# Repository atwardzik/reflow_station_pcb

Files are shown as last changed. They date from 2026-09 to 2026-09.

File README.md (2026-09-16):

# Reflow Station

This project is currently in a prototype stage. It features PCB project of
basic reflow station utilizing 4 phase-controlled triacs steering with attached
heaters. The temperature is controlled by the STM32F469VIT6 MCU with attached
ADS1118 thermocouple interfaces.

## Schematic

Circuit Diagram

## License
CC BY-NC-SA 4.0

Copyright (C) 2026, Artur Twardzik

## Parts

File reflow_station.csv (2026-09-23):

Reference | Qty | Value | Mfr.No | Replacement_Mfr.No | Description | Package | Footprint | Datasheet | Supplier | Supplier_Link | JLCPCB_PartNo | Additional_Info
C1 | 1 | 100n 1kV | R474N31005001K |  | Unpolarized capacitor: 100nF 440VAC X2 10% polypropylene |  | reflow_station_library:R474N31005001K | https://www.tme.eu/Document/74c9fedd37d4aad2db2d48e5f5684533/Datasheet-R474N31005001K.pdf | TME | https://www.tme.eu/pl/details/r474n31005001k/kondensatory-foliowe-tht/kemet/
C2,C13,C14,C17,C23,C25,C26,C28,C29,C31,C33,C34,C36,C37,C39,C41,C46,C47,C48,C49,C50,C51,C52,C53,C54,C56,C58,C59 | 28 | 100n | CL05B104KB54PNC |  | Unpolarized capacitor: 100nF 50V X7R ±10% ceramic | 0402 | reflow_station_library:C_0402_1005Metric |  | JLCPCB | https://jlcpcb.com/partdetail/291005-CL05B104KB54PNC/C307331 | C307331
C3 | 1 | 47u | C2220C476M3R2CAUTO |  | Unpolarized capacitor: 47uF 25V X7R ±20% ceramic | 2220 | reflow_station_library:C_2220_5750Metric_Pad1.97x5.40mm_HandSolder | https://www.tme.eu/Document/458b498f8990c968c05ae31cff6842ca/C2220C476M3R2CAUTO.pdf | TME | https://www.tme.eu/pl/en/details/c2220c476m3r2cauto/mlcc-smd-capacitors/kemet/
C4,C7 | 2 | 10u | CL31A106KBHNNNE |  | Unpolarized capacitor: 10uF 50V X5R 10% ceramic | 1206 | reflow_station_library:C_1206_3216Metric_Pad1.33x1.80mm_HandSolder |  | JLCPCB | https://jlcpcb.com/partdetail/14236-CL31A106KBHNNNE/C13585 | C13585
C5,C40 | 2 | 47u | CL31A476MPHNNNE |  | Unpolarized capacitor: 47uF 10V X5R 20% ceramic | 1206 | reflow_station_library:C_1206_3216Metric_Pad1.33x1.80mm_HandSolder |  | JLCPCB | https://jlcpcb.com/partdetail/97327-CL31A476MPHNNNE/C96123 | C96123
C6,C11 | 2 | 430p | GCM1555C1H431JA16D |  | Unpolarized capacitor: 430pF 50V 5% ceramic | 0402 | reflow_station_library:C_0402_1005Metric |  | JLCPCB | https://jlcpcb.com/partdetail/2285629-GCM1555C1H431JA16D/C2193561 | C2193561
C8 | 1 | 22u | CL31A226KAHNNNE |  | Unpolarized capacitor: 22uF 25V X5R 10% ceramic | 1206 | reflow_station_library:C_1206_3216Metric |  | JLCPCB | https://jlcpcb.com/partdetail/13537-CL31A226KAHNNNE/C12891 | C12891
C9 | 1 | 470p | 0603B471K500NT |  | Unpolarized capacitor: 470pF 50V X7R 10% ceramic | 0603 | reflow_station_library:C_0603_1608Metric |  | JLCPCB | https://jlcpcb.com/partdetail/1972-0603B471K500NT/C1620 | C1620
C10 | 1 | 220u | RVT1V221M0810ZY |  | Polarized capacitor: 220uF 50V 20% aluminum electrolytic | D8xL10.5mm | reflow_station_library:CP_Elec_8x10.5 |  | JLCPCB | https://jlcpcb.com/partdetail/ChengTao-RVT1V221M0810ZY/C46527540 | C46527540
C12,C45 | 2 | 4.7u | CL21A475KAQNNNE |  | Unpolarized capacitor: 4.7uF 25V X5R 10% ceramic | 0805 | reflow_station_library:C_0805_2012Metric |  | JLCPCB | https://jlcpcb.com/partdetail/2131-CL21A475KAQNNNE/C1779 | C1779
C15,C16,C24,C27,C32,C35,C42,C43,C44,C57,C60 | 11 | 1u | CL05A105KA5NQNC |  | Unpolarized capacitor: 1uF 25V X5R 10% ceramic | 0402 | reflow_station_library:C_0402_1005Metric |  | JLCPCB | https://jlcpcb.com/partdetail/53938-CL05A105KA5NQNC/C52923 | C52923
C18 | 1 | 2.2n | 0603B222K500NT |  | Unpolarized capacitor: 2.2nF 50V X7R 10% ceramic | 0603 | reflow_station_library:C_0603_1608Metric |  | JLCPCB | https://jlcpcb.com/partdetail/1956-0603B222K500NT/C1604 | C1604
C19,C20,C21,C22 | 4 | 10n 305V X2 | B32921C3103M189 |  | Unpolarized capacitor: 10nF 305VAC X2 20% polypropylene |  | reflow_station_library:B32921C3103M000 | https://www.tme.eu/Document/b68f0c52455388a5f3f01ef7d5bbddae/x2_b32921_928.pdf | TME | https://www.tme.eu/pl/details/b32921c3103m189/kondensatory-foliowe-tht/tdk/
C30,C38 | 2 | 10n | CL05B103KB5NNNC |  | Unpolarized capacitor: 10nF 50V X7R 10% ceramic | 0402 | reflow_station_library:C_0402_1005Metric |  | JLCPCB | https://jlcpcb.com/partdetail/15869-CL05B103KB5NNNC/C15195 | C15195
C55,C63,C64 | 3 | 2.2u | CL10A225KO8NNNC |  | Unpolarized capacitor: 2.2uF 16V X5R 10% ceramic | 0603 | reflow_station_library:C_0603_1608Metric |  | JLCPCB | https://jlcpcb.com/partdetail/24366-CL10A225KO8NNNC/C23630 | C23630
C61,C62 | 2 | 10p | CL05C100JB5NNNC |  | Unpolarized capacitor: 10pF 50V C0G 5% ceramic | 0402 | reflow_station_library:C_0402_1005Metric |  | JLCPCB | https://jlcpcb.com/partdetail/33914-CL05C100JB5NNNC/C32949 | C32949
C65,C66 | 2 | 1.5p | 0402CG1R5C500NT |  | Unpolarized capacitor: 1.5pF 50V C0G ceramic | 0402 | reflow_station_library:C_0402_1005Metric |  | JLCPCB | https://jlcpcb.com/partdetail/1904-0402CG1R5C500NT/C1552 | C1552
D1,D2,D4,D10,D11,D13 | 6 | LED | KT-0603R |  | Light emitting diode: red | 0603 | reflow_station_library:LED_0603_1608Metric |  | JLCPCB | https://jlcpcb.com/partdetail/Hubei_KENTOElec-KT0603R/C2286 | C2286
D3 | 1 | MB10S | MB10S-50MIL |  | Single-Phase Diode Bridge Rectifier | MBS | reflow_station_library:SOP240P700X300-4N |  | JLCPCB | https://jlcpcb.com/partdetail/2865-MB10S50MIL/C2488 | C2488
D5 | 1 | BAT54S | BAT54SLT1G |  | Dual Series Schottky Barrier Diodes | SOT-23 | reflow_station_library:SOT-23 |  | JLCPCB | https://jlcpcb.com/partdetail/onsemi-BAT54SLT1G/C19726 | C19726
D6,D7,D8 | 3 | 1N4148WS |  |  | 75V 0.15A Fast switching Diode, SOD-323 |  | Diode_SMD:D_SOD-323 | https://www.vishay.com/docs/85751/1n4148ws.pdf
D9,D12,D14 | 3 | LED | KT-0805G,KT-0805W,KT-0805Y |  | Light emitting diode: green,Light emitting diode: white,Light emitting diode: yellow | 0805 | reflow_station_library:LED_0805_2012Metric |  | JLCPCB | https://jlcpcb.com/partdetail/Hubei_KENTOElec-KT0805G/C2297,https://jlcpcb.com/partdetail/Hubei_KENTOElec-KT0805W/C34499,https://jlcpcb.com/partdetail/Hubei_K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 | C2296,C2297,C34499
HS1,HS2,HS3,HS4 | 4 | Heatsink | SK 75 50 SA-TO 220 |  | Heatsink with electrical connection, 2 pin |  | reflow_station_library:Heatsink_Stonecold_HS-132_32x14mm_2xFixation1.5mm |  | TME | https://www.tme.eu/pl/en/details/sk75_50_sa-to220/heatsinks/fischer-elektronik/sk-75-50-sa-to-220/
IC1 | 1 | MP100LGN-Z | MP100LGN-Z |  | AC/DC Converters Offline Inductorless regulator, Low EMI | SOIC-8 | reflow_station_library:SOIC127P600X170-9N | https://www.monolithicpower.com/en/documentview/productdocument/index/version/2/document_type/Datasheet/lang/en/sku/MP100L/document_id/11 | JLCPCB | https://jlcpcb.com/partdetail/Monolithic_PowerSystems-MP100LGNZ/C17183900 | C17183900
IC2 | 1 | AMC23C10DWVR | AMC23C10DWVR |  | Analog Comparators Fast-response, reinforced, isolated differential comparator with open-drain and push-pull outputs | SOIC-8 | reflow_station_library:SOIC127P1150X280-8N | https://www.ti.com/lit/ds/symlink/amc23c10.pdf?HQS=dis-mous-null-mousermode-dsf-pf-null-wwe&ts=1691395362663 | JLCPCB | https://jlcpcb.com/partdetail/TexasInstruments-AMC23C10DWVR/C5943166 | C5943166
J1 | 1 | 1731734 | 1731734 |  | GMKDS 3/ 3-7,62 - Printed circuit board terminal, nominal current: 24 A, rated voltage (III/2): 630 V, nominal cross section: 2.5 mm<sup>2</sup>, number of potentials: 3, number of rows: 1, number of positions per row: 3, product range: GMKDS 3, pitch: 7.62 mm, connection method: Screw connection with tension sleeve, screw head form: L Slotted, mounting: Wave soldering, conductor/PCB connection direction: 0 , color: green, Pin layout: Linear pinning, Solder pin [P]: 5 mm, number of solder pins per potentia |  | reflow_station_library:1731734 | https://www.phoenixcontact.com/en-us/products/printed-circuit-board-terminal-gmkds-3-3-762-1731734?type=pdf | TME | https://www.tme.eu/pl/details/gmkds3_3-7.62/listwy-zaciskowe-do-druku/phoenix-contact/1731734/
J2,J3,J4,J5 | 4 | 1707027 | 1731721 |  | GMKDS 3/ 2-7,62 - Printed circuit board terminal, nominal current: 24 A, rated voltage (III/2): 630 V, nominal cross section: 2.5 mm<sup>2</sup>, number of potentials: 2, number of rows: 1, number of positions per row: 2, product range: GMKDS 3, pitch: 7.62 mm, connection method: Screw connection with tension sleeve, screw head form: L Slotted, mounting: Wave soldering, conductor/PCB connection direction: 0 , color: green, Pin layout: Linear pinning, Solder pin [P]: 5 mm, number of solder pins per potentia |  | reflow_station_library:1731721 | https://www.phoenixcontact.com/en-us/products/printed-circuit-board-terminal-gmkds-3-2-762-1731721?type=pdf | TME | https://www.tme.eu/pl/details/gmkds3_2-7.62/listwy-zaciskowe-do-druku/phoenix-contact/1731721/
J6,J7,J8,J9 | 4 | DG301-5.0-02P-12-00A_H_ | DG301-5.0-02P-12-00A(H) |  | PCB terminal block; angled 90; 5mm; ways: 2; on PCBs; 1.5mm2; blue |  | reflow_station_library:DG3015002P1200AH | https://www.tme.com/Document/72ad9f371bb0c16572574ac47903b3a1/DG301-5.0.pdf | TME | https://www.tme.eu/pl/en/details/dg301-5.0-2p12/pcb-terminal-blocks/degson-electronics/dg301-5-0-02p-12-00a-h/
J10 | 1 | USB_A |  |  | USB Type A connector |  | reflow_station_library:USB_A_Molex_67643_Horizontal | https://www.tme.eu/Document/28949cd128764504b86904217dc06d83/MX-67643-0910.pdf | TME | https://www.tme.eu/pl/en/details/mx-67643-0910/usb-ieee1394-connectors/molex/67643-0910/
J11 | 1 | USB_C_Receptacle_USB2.0_16P | USB-TYPE-C-018 |  | USB 2.0-only 16P Type-C Receptacle connector |  | reflow_station_library:USB-C_SMD-TYPE-C-31-M-12 | https://www.usb.org/sites/default/files/documents/usb_type-c.zip | JLCPCB | https://jlcpcb.com/partdetail/DEALON-USB_TYPE_C018/C2927038 | C2927038
J12 | 1 | Conn_ARM_JTAG_SWD_10 | HX JN1.27-2x5P ZZ H4.9 |  | Cortex Debug Connector, standard ARM Cortex-M SWD and JTAG interface |  | reflow_station_library:CONN-TH_10P-P1.27_HX-JN1.27-2X5P-ZZ-H4.9 | http://infocenter.arm.com/help/topic/com.arm.doc.ddi0314h/DDI0314H_coresight_components_trm.pdf | JLCPCB | https://jlcpcb.com/partdetail/hanxia-HX_JN1_27_2x5P_ZZ_H49/C42372547 | C42372547
J13 | 1 | F52Q-1A7H1-11015 | F52Q-1A7H1-11015 |  | Flex Connector, 1.00mm Pitch, Height 2.00mm, Right angle, Slider type, ZIF, Upper contact, 15 position , Without MYLAR |  | reflow_station_library:F52Q1A7H111015 | https://cdn.amphenol-cs.com/media/wysiwyg/files/drawing/f52q.pdf | MOUSER | https://www.mouser.pl/en/ProductDetail/Amphenol-Aorora/F52Q-1A7H1-11015?qs=xZ%2FP%252Ba9zWqZztqleDXVpTA%3D%3D
L1,L2,L3,L4,L5 | 5 | 33R @ 100MHz | BLM18PG330SN1D |  | Inductor: 33R @ 100MHz, EMI filter |  | reflow_station_library:L_1206_3216Metric_Pad1.22x1.90mm_HandSolder |  | JLCPCB | https://jlcpcb.com/partdetail/MurataElectronics-BLM18PG330SN1D/C88984 | C88984
L6 | 1 | 600R @ 100MHz | FCM1608KF-601T03 | BLM18AG601SN1D | Inductor: 600R @ 100MHz, digital and analog voltage filtering |  | reflow_station_library:L_0603_1608Metric |  | JLCPCB | https://jlcpcb.com/partdetail/TAITECH-FCM1608KF601T03/C141723 | C141723 | C19330 is in greater availability
LS1 | 1 | PS1240P02BT | PS1240P02BT |  | Piezoelectric Buzzers, Sound Pressure Level=70dB min, Freq.=4000Hz nom |  | reflow_station_library:PS1240P02BT | https://product.tdk.com/system/files/dam/doc/product/sw_piezo/sw_piezo/piezo-buzzer/catalog/piezoelectronic_buzzer_ps_en.pdf | MOUSER | https://www.mouser.pl/en/ProductDetail/TDK/PS1240P02BT?qs=d7g9p1yFhWaZXSY9MjKMkw%3D%3D
M1,M2,M3,M4 | 4 | Fan_CPU_4pin | B4B-PH-K-S (LF)(SN) |  | Connector: wire-board socket male 4 pin 2A |  | reflow_station_library:JST_PH_B4B-PH-K_1x04_P2.00mm_Vertical | https://www.tme.eu/Document/bde47a97a79ef7b2143e7f603cd40725/PH.pdf | TME | https://www.tme.eu/pl/details/b4b-ph-k-s/zlacza-sygnalowe-raster-2-00mm/jst/b4b-ph-k-s-lf-sn/
Q1,Q2,Q3,Q4 | 4 | BTA16-600B | BTA16-600BRG | BTA08-600BRG; T3035H-8I | Triac: 16A 50mA 600V pin 2 bent | TO-220 | reflow_station_library:TO-220-3_Vertical_Staggered | https://www.tme.eu/Document/f612b70f30f519380bd53616c2407b4b/BTA16_BTB16_T16xx.pdf | TME | https://www.tme.eu/pl/en/details/bta16-600brg/triacs/stmicroelectronics/ |  | T3035H-8I has Igt=35mA but has max Tj at 150 'C
Q5 | 1 | KSC1815YTA | KSC1815YTA |  | Bipolar transistor: NPN 50V 0.15 0.4W | TO92 | reflow_station_library:TO-92L_Inline_Wide | https://www.tme.eu/Document/4d6f25bc413f5cea15d81ed94c626a86/KSC1815.pdf | TME | https://www.tme.eu/pl/en/details/ksc1815yta/npn-tht-transistors/onsemi/
R1,R59 | 2 | 1k | 0402WGF1001TCE |  | Resistor: 1kOhm 50V 62.5mW 1% | 0402 | reflow_station_library:R_0402_1005Metric |  | JLCPCB | https://jlcpcb.com/partdetail/12256-0402WGF1001TCE/C11702 | C11702
R2 | 1 | 510 | 0402WGF5100TCE |  | Resistor: 510Ohm 50V 62.5mW 1% | 0402 | reflow_station_library:R_0402_1005Metric |  | JLCPCB | https://jlcpcb.com/partdetail/25866-0402WGF5100TCE/C25123 | C25123
R3 | 1 | 523k | 0402WGF5233TCE |  | Resistor: 523kOhm 50V 62.5mW 1% | 0402 | reflow_station_library:R_0402_1005Metric |  | JLCPCB | https://jlcpcb.com/partdetail/27760-0402WGF5233TCE/C27011 | C27011
R4 | 1 | 100 3W | PMR03SJ0101A19 |  | Resistor: 100Ohm 750V 3W 5% power metal |  | reflow_station_library:R_Axial_DIN0516_L15.5mm_D5.0mm_P20.32mm_Horizontal |  | TME | https://www.tme.eu/pl/details/pmr3s-100r/rezystory-tht/royalohm/pmr03sj0101a19/
R5,R6,R7,R12,R13 | 5 | 100k | 0402WGF1003TCE |  | Resistor: 100kOhm 50V 62.5mW 1% | 0402 | reflow_station_library:R_0402_1005Metric |  | JLCPCB | https://jlcpcb.com/partdetail/26484-0402WGF1003TCE/C25741 | C25741
R8,R60,R61,R62,R63,R64,R65 | 7 | 330 | 0402WGF3300TCE |  | Resistor: 330Ohm 50V 62.5mW 1% | 0402 | reflow_station_library:R_0402_1005Metric |  | JLCPCB | https://jlcpcb.com/partdetail/25847-0402WGF3300TCE/C25104 | C25104
R9 | 1 | 309k | 0402WGF3093TCE |  | Resistor: 309kOhm 50V 62.5mW 1% | 0402 | reflow_station_library:R_0402_1005Metric |  | JLCPCB | https://jlcpcb.com/partdetail/123815-0402WGF3093TCE/C122546 | C122546
R10 | 1 | 90.9k | 0402WGF9092TCE |  | Resistor: 90.9kOhm 50V 62.5mW 1% | 0402 | reflow_station_library:R_0402_1005Metric |  | JLCPCB | https://jlcpcb.com/partdetail/27738-0402WGF9092TCE/C26989 | C26989
R11 | 1 | 10.2k | 0402WGF1022TCE |  | Resistor: 10.2kOhm 50V 62.5mW 1% | 0402 | reflow_station_library:R_0402_1005Metric |  | JLCPCB | https://jlcpcb.com/partdetail/12214-0402WGF1022TCE/C11660 | C11660
R14 | 1 | 10 | 0603WAF100JT5E |  | Resistor: 10Ohm 75V 100mW 1% | 0603 | reflow_station_library:R_0603_1608Metric |  | JLCPCB | https://jlcpcb.com/partdetail/23586-0603WAF100JT5E/C22859 | C22859
R15,R16,R17 | 3 | 1.09M | TNPW12061M09BEEN |  | Resistor: 1.09MOhm 200V 520mW 0.1% | 1206 | reflow_station_library:R_1206_3216Metric_Pad1.30x1.75mm_HandSolder |  | MOUSER | https://www.mouser.pl/en/ProductDetail/Vishay/TNPW12061M09BEEN?qs=PqoDHHvF6499FjexZcqXEA%3D%3D
R18 | 1 | 10k | 1206W4F1002T5E |  | Resistor: 10kOhm 200V 250mW 1% | 1206 | reflow_station_library:R_1206_3216Metric_Pad1.30x1.75mm_HandSolder |  | JLCPCB | https://jlcpcb.com/partdetail/18590-1206W4F1002T5E/C17902 | C17902
R19,R20,R25,R26 | 4 | 220 | 0402WGF2200TCE |  | Resistor: 220Ohm 50V 62.5mW 1% | 0402 | reflow_station_library:R_0402_1005Metric |  | JLCPCB | https://jlcpcb.com/partdetail/25834-0402WGF2200TCE/C25091 | C25091
R21,R22,R27,R28 | 4 | 470 1W fusible | FRN01WK0471A10 |  | Resistor: 470Ohm 1W 10% fusible |  | reflow_station_library:R_Axial_DIN0411_L9.9mm_D3.6mm_P15.24mm_Horizontal |  | TME | https://www.tme.eu/pl/details/nfr1w-470r/rezystory-tht/royalohm/frn01wk0471a10/
R23,R24,R29,R30 | 4 | 33 0.5W | 1210W2F330JT5E |  | Resistor: 33Ohm 200V 500mW 1% | 1210 | reflow_station_library:C_1210_3225Metric |  | JLCPCB | https://jlcpcb.com/partdetail/395749-1210W2F330JT5E/C407192 | C407192
R31,R32,R33,R34,R39,R40,R41,R42 | 8 | 1M | 0402WGF1004TCE |  | Resistor: 1MOhm 50V 62.5mW 1% | 0402 | reflow_station_library:R_0402_1005Metric |  | JLCPCB | https://jlcpcb.com/partdetail/26826-0402WGF1004TCE/C26083 | C26083
R35,R36,R37,R38,R43,R44,R45,R46 | 8 | 500 | RT0402FRE07500RL |  | Resistor: 500Ohm 63mW 1% | 0402 | reflow_station_library:R_0402_1005Metric |  | JLCPCB | https://jlcpcb.com/partdetail/YAGEO-RT0402FRE07500RL/C6460545 | C6460545
R47,R48,R53,R54,R55,R56,R57,R58,R75,R76,R77,R78,R79,R80,R81,R82,R84,R85 | 18 | 10k | 0402WGF1002TCE |  | Resistor: 10kOhm 50V 62.5mW 1% | 0402 | reflow_station_library:R_0402_1005Metric |  | JLCPCB | https://jlcpcb.com/partdetail/26487-0402WGF1002TCE/C25744 | C25744
R49,R50 | 2 | 5.1k | 0402WGF5101TCE |  | Resistor: 5.1kOhm 50V 62.5mW 1% | 0402 | reflow_station_library:R_0402_1005Metric |  | JLCPCB | https://jlcpcb.com/partdetail/26648-0402WGF5101TCE/C25905 | C25905
R51 | 1 | 33k | 0402WGF3302TCE |  | Resistor: 33kOhm 50V 62.5mW 1% | 0402 | reflow_station_library:R_0402_1005Metric |  | JLCPCB | https://jlcpcb.com/partdetail/26522-0402WGF3302TCE/C25779 | C25779
R52 | 1 | 82k | 0603WAF8202T5E |  | Resistor: 82kOhm 75V 100mW 1% | 0603 | reflow_station_library:R_0603_1608Metric |  | JLCPCB | https://jlcpcb.com/partdetail/23981-0603WAF8202T5E/C23254 | C23254
R66 | 1 | 47k | 0402WGJ0473TCE |  | Resistor: 47kOhm 50V 62.5mW 1% | 0402 | reflow_station_library:R_0402_1005Metric |  | JLCPCB | https://jlcpcb.com/partdetail/26306-0402WGJ0473TCE/C25563 | C25563
R67,R68,R69,R70,R71,R72,R73,R74,R83 | 9 | 0 | 0402WGF0000TCE |  | Resistor: 0Ohm 50V 62.5mW 1% | 0402 | reflow_station_library:R_0402_1005Metric |  | JLCPCB | https://jlcpcb.com/partdetail/17853-0402WGF0000TCE/C17168 | C17168
RV1,RV2,RV3,RV4 | 4 | 350VAC | ERZE10A561 |  | Voltage dependent resistor 350VAC 4.5kA |  | reflow_station_library:RV_Disc_D12mm_W3.9mm_P7.5mm |  | TME | https://www.tme.eu/pl/details/erze10a561/warystory-tht/panasonic/
SW2,SW3,SW4 | 3 | SW_SPST | B2B-PH-K-S (LF)(SN) |  | Connector: wire-board socket male 2 pin 2A |  | reflow_station_library:JST_PH_B2B-PH-K_1x02_P2.00mm_Vertical |  | TME | https://www.tme.eu/pl/details/b2b-ph-k-s/zlacza-sygnalowe-raster-2-00mm/jst/b2b-ph-k-s-lf-sn/
SW5 | 1 | SW_DIP_x08 | DS-08 |  | 8x DIP Switch, Single Pole Single Throw (SPST) switch, small symbol |  | reflow_station_library:SW_DIP_SPSTx08_Slide_9.78x22.5mm_W7.62mm_P2.54mm |  | TME | https://www.tme.eu/pl/details/ds-08/przelaczniki-typu-dip-switch/ninigi/
SW6 | 1 | SW_Push | TS-1088-AR02016 |  | Push button switch 2 pin |  | reflow_station_library:SW_TS-1088-AR02016 |  | JLCPCB | https://jlcpcb.com/partdetail/XUNPU-TS_1088AR02016/C720477 | C720477
SW7,SW8 | 2 | SW_SPDT | ESP1010 |  | Switch, single pole double throw |  | reflow_station_library:ESP1010 |  | TME | https://www.tme.eu/pl/details/esp1010/przelaczniki-suwakowe/ece/
U1,U3 | 2 | TPS82130 | TPS82130SILR |  | Voltage Regulator: programmable step down, OC protection, 3A | USIP-8 | reflow_station_library:Texas_SIL0008D_MicroSiP-8-1EP_2.8x3mm_P0.65mm_EP1.1x1.9mm_ThermalVias |  | JLCPCB | https://jlcpcb.com/partdetail/TexasInstruments-TPS82130SILR/C473914 | C473914
U2 | 1 | RAC20-12SK | RAC20-12SK |  | 20 Watt Single Output AC/DC power supply 12V 1670mA |  | reflow_station_library:Converter_ACDC_Recom_RAC20-xxSK_THT | https://recom-power.com/pdf/Powerline_AC-DC/RAC20-K.pdf | TME | https://www.tme.eu/pl/details/rac20-12sk/przetwornice-ac-dc-na-pcb/recom/
U4,U5,U6,U7 | 4 | MOC3052 | MOC3052S-TA1 |  | Optocoupler: without zero detection circuit 20mA | SMD-6P | reflow_station_library:SMDIP-6_W9.53mm |  | JLCPCB | https://jlcpcb.com/partdetail/LiteOn-MOC3052STA1/C115471 | C115471
U8,U9 | 2 | ADS1118IDGS | ADS1118IDGST |  | Ultrasmall, Low-Power, SPI-Compatible, 16-Bit Analog-to-Digital Converter with Internal Reference and Temperature Sensor, VSSOP-10 | VSSOP-10-0.5mm | reflow_station_library:TSSOP-10_3x3mm_P0.5mm | http://www.ti.com/lit/ds/symlink/ads1118.pdf | JLCPCB | https://jlcpcb.com/partdetail/TexasInstruments-ADS1118IDGST/C701612 | C701612
U10 | 1 | TPS2051BDBVR | TPS2051BDBVR |  | OC Protection IC | SOT-23-5 | reflow_station_library:DBV0005A_N | https://www.ti.com/lit/gpn/tps2051b | JLCPCB | https://jlcpcb.com/partdetail/TexasInstruments-TPS2051BDBVR/C24593 | C24593
U11,U12,U13 | 3 | RCLAMP0504F.TCT | RCLAMP0504F.TCT |  | ESD Protection TVS Diodes | SC-70-6L | reflow_station_library:SC70-6L_RCLAMP_SEM | RCLAMP0504F.TCT | JLCPCB | https://jlcpcb.com/partdetail/SEMTECH-RCLAMP0504FTCT/C132257 | C132257
U14 | 1 | STM32F469VIT6 | STM32F469VIT6 |  | MCU: STM32F469 ARM Cortex-M4 180MHz 384KB SRAM 2MB Flash | LQFP-100(14x14) | reflow_station_library:LQFP-100_14x14mm_P0.5mm |  | JLCPCB | https://jlcpcb.com/partdetail/STMicroelectronics-STM32F469VIT6/C2970187 | C2970187
Y1 | 1 | 25MHz | X322525MOB4SI |  | XOSC: 25MHz 50Ohm 4 pin | SMD3225-4P | reflow_station_library:Crystal_SMD_3225-4Pin_3.2x2.5mm |  | JLCPCB | https://jlcpcb.com/partdetail/YXC_CrystalOscillators-X322525MOB4SI/C9006 | C9006
Y2 | 1 | 32.768kHz | NX3215SA 32.768KHZ EXS00A-MU00525 | NX3215SA 32.768KHZ EXS00A-MU00525 | XOSC: 32.768kHz 70kOhm 2 pin | SMD3215-2p | reflow_station_library:Crystal_SMD_3215-2Pin_3.2x1.5mm |  | JLCPCB | https://jlcpcb.com/partdetail/C528987 | C528987

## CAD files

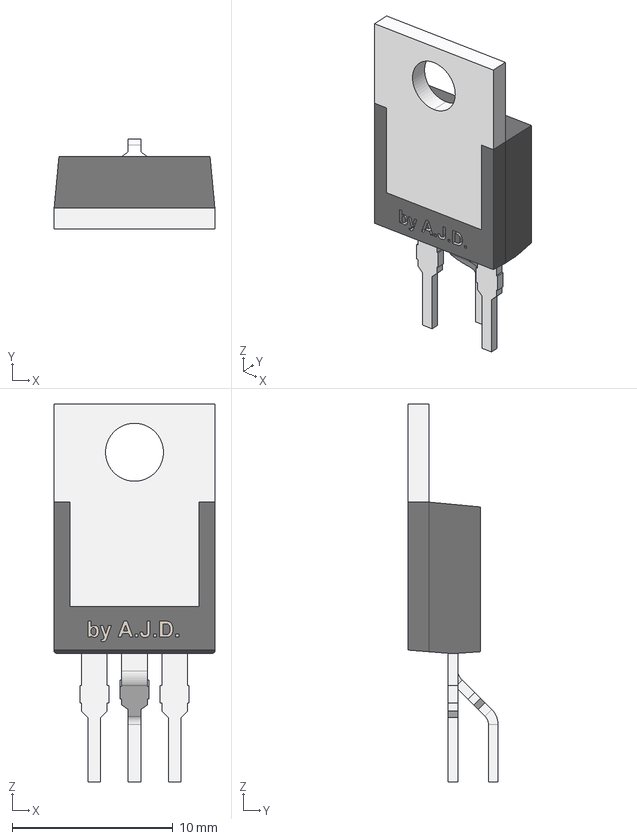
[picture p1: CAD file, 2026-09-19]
parts_external/TO-220_V3PBS-1x2,5_a.STEP
10.0 x 5.60 x 23.5 mm

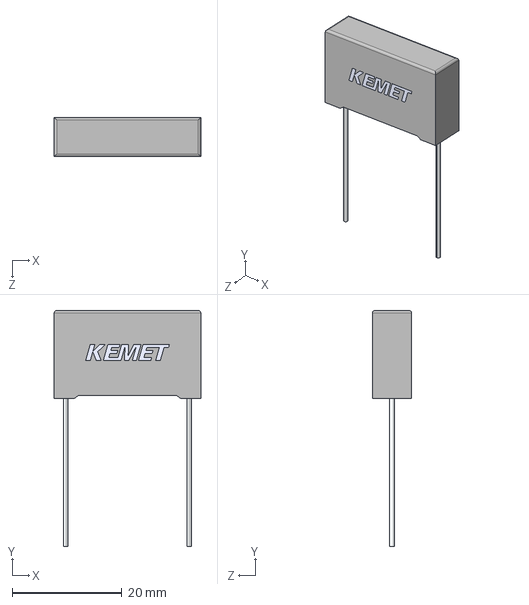
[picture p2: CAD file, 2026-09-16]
parts_external/R474N31005001K.stp
26.8 x 43.1 x 7.20 mm

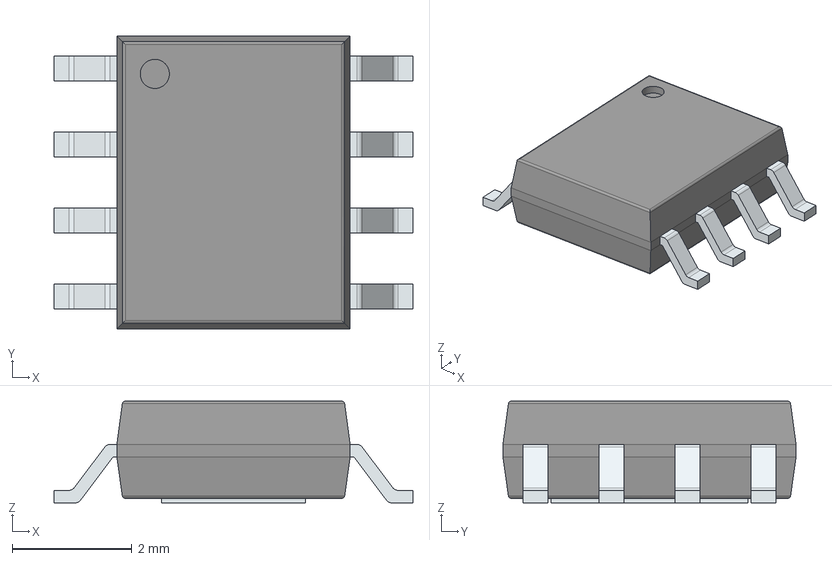
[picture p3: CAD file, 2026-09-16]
parts_external/MP100LGN-Z.stp
6.00 x 4.90 x 1.70 mm
PinsArrayLR
ThermalPad

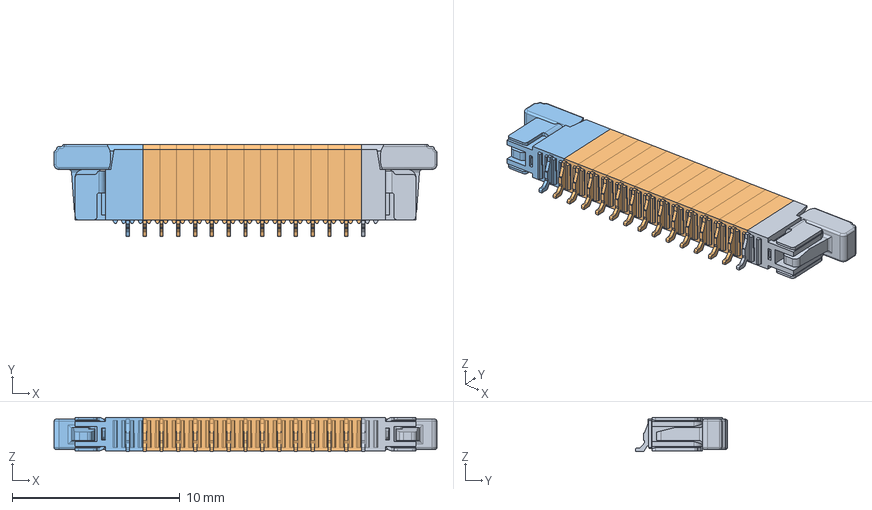
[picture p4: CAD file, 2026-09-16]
parts_external/F52Q-1A7H1-11015.stp
22.8 x 5.50 x 2.05 mm
F52Q_L
F52Q_M x 13
F52Q_R

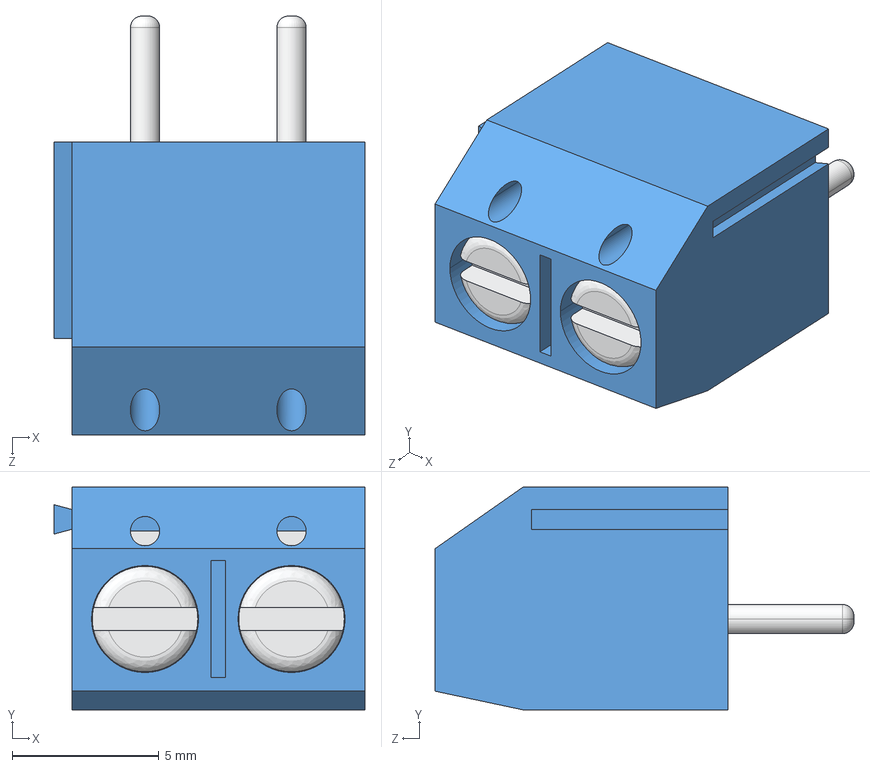
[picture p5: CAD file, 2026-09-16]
parts_external/DG301-5.0-02P-12-00A_H_.stp
10.6 x 7.60 x 14.3 mm
DG301-5.0-02
DG301-5.0-pin x 2
DG301-5.0-wire-guard x 2
DG301-5.0-screw x 2

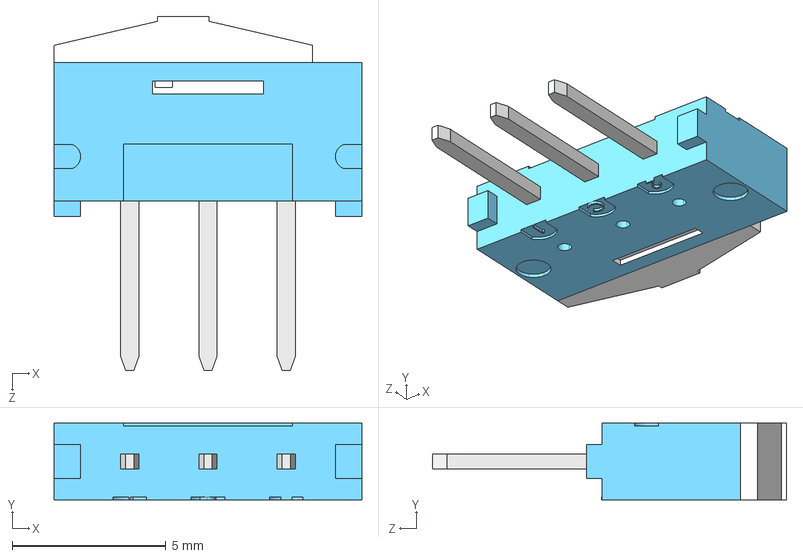
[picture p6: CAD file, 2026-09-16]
parts_external/ESP1010.stp
10.0 x 2.50 x 11.5 mm

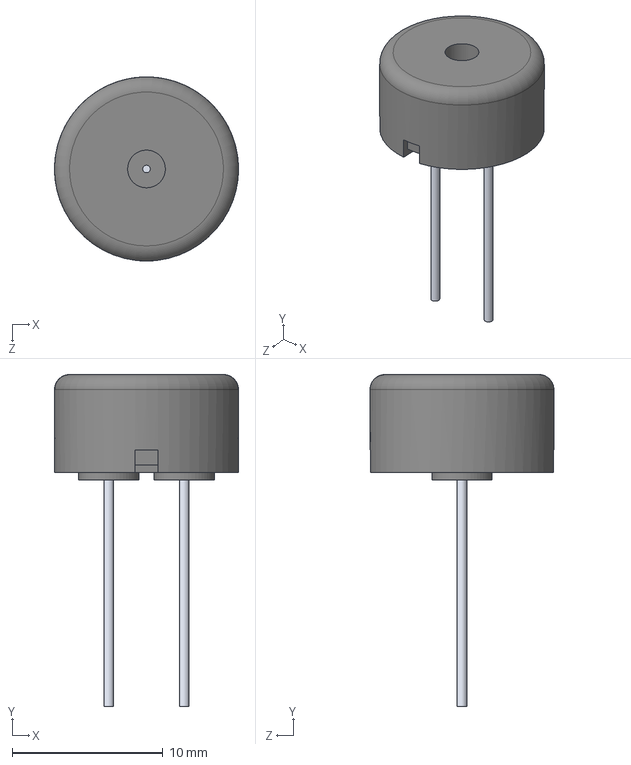
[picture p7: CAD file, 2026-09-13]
parts_external/PS1240P02BT.stp
12.2 x 22.0 x 12.2 mm

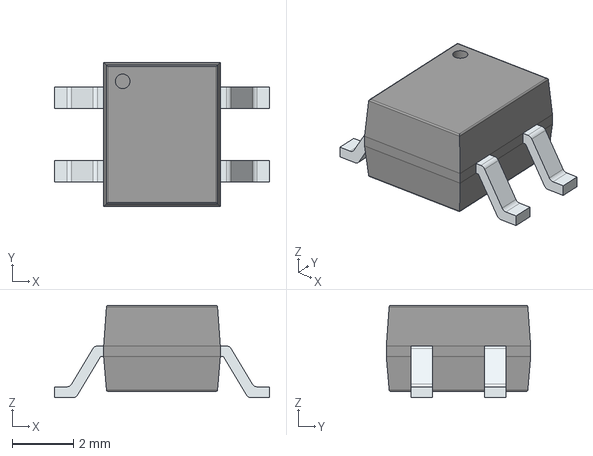
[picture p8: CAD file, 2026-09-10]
parts_external/MB10S.stp
7.00 x 4.70 x 3.00 mm
PinsArrayLR

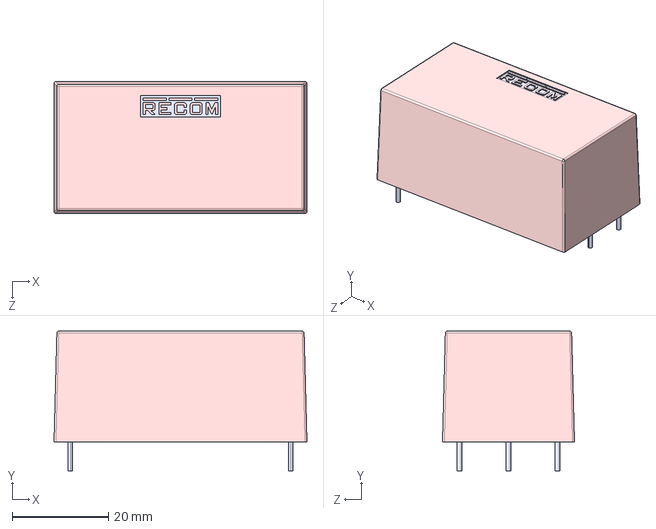
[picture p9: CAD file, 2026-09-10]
parts_external/RAC20-12SK.stp
52.5 x 29.0 x 27.4 mm

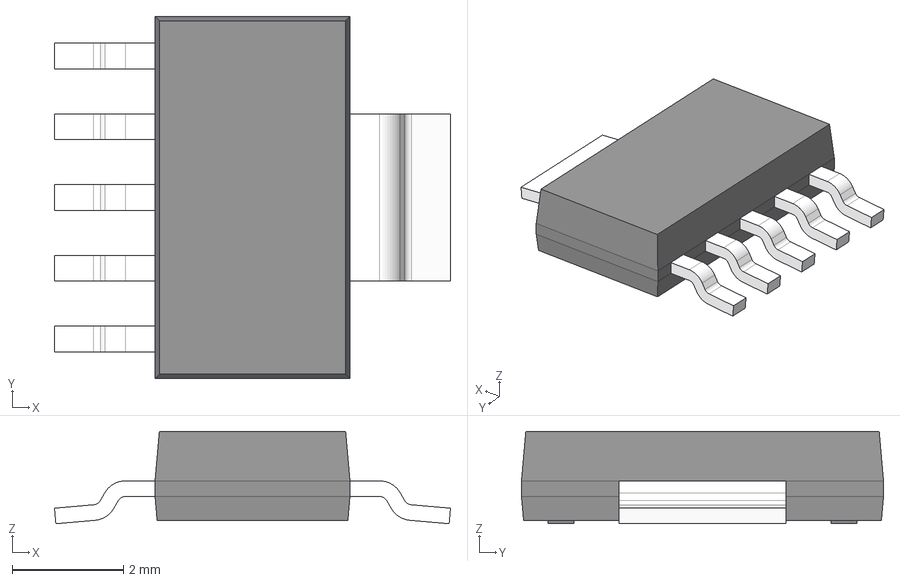
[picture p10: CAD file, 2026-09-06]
parts_external/DCQ0006A.stp
7.11 x 6.50 x 1.66 mm
LEAD x 5
LEAD_WIDE

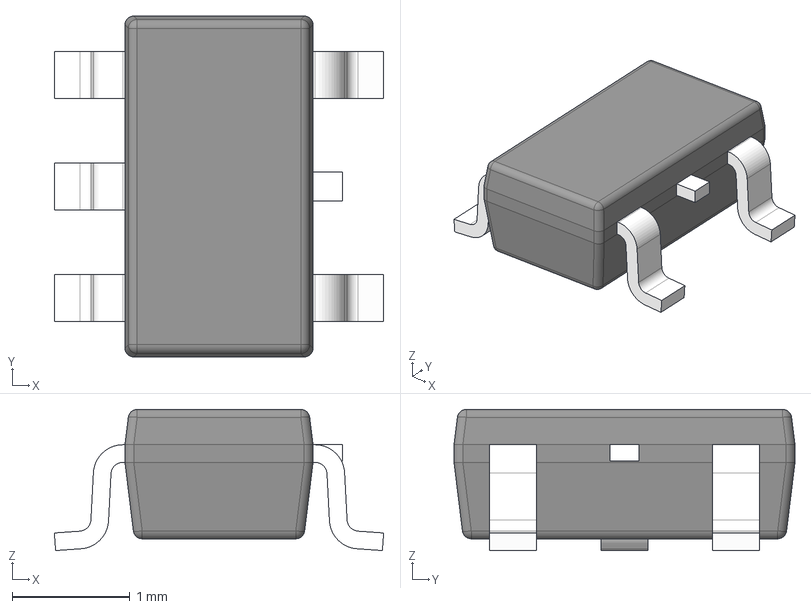
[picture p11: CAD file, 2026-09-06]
parts_external/DBV0005A.stp
2.80 x 2.90 x 1.20 mm
BODY-SOT
LEAD-SOT x 5
LEAD-DUMMY

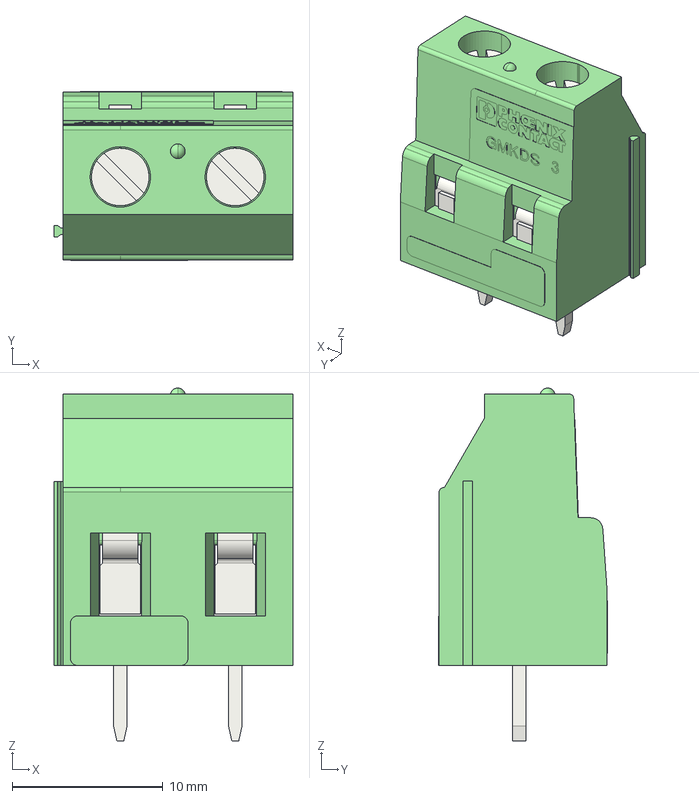
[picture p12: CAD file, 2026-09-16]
parts_external/1731721.stp
15.8 x 11.2 x 23.4 mm

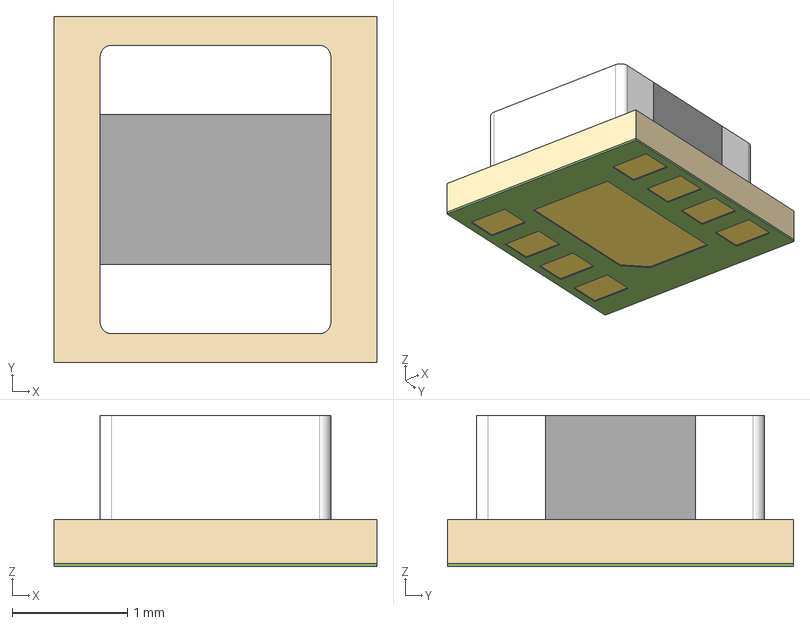
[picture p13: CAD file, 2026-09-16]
parts_external/TPS82130SILR.stp
2.80 x 3.00 x 1.31 mm
SOLDERMASK-SIP
METAL-SIL0008D
SUBSTRATE-SIP
INDUCTOR-BODY-MLV
INDUCTOR-TERMNL-MLV x 2

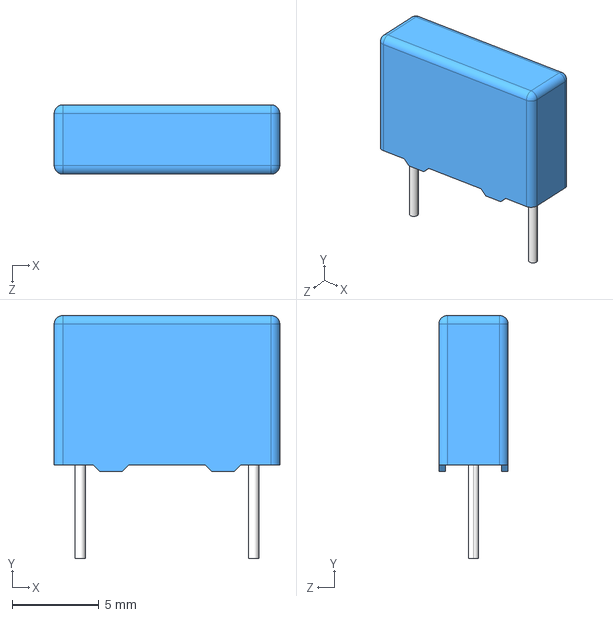
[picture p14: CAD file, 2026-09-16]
parts_external/B32921C3103M189.stp
13.0 x 14.0 x 4.00 mm

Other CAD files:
parts_external/1707027.stp
parts_external/1731734.stp

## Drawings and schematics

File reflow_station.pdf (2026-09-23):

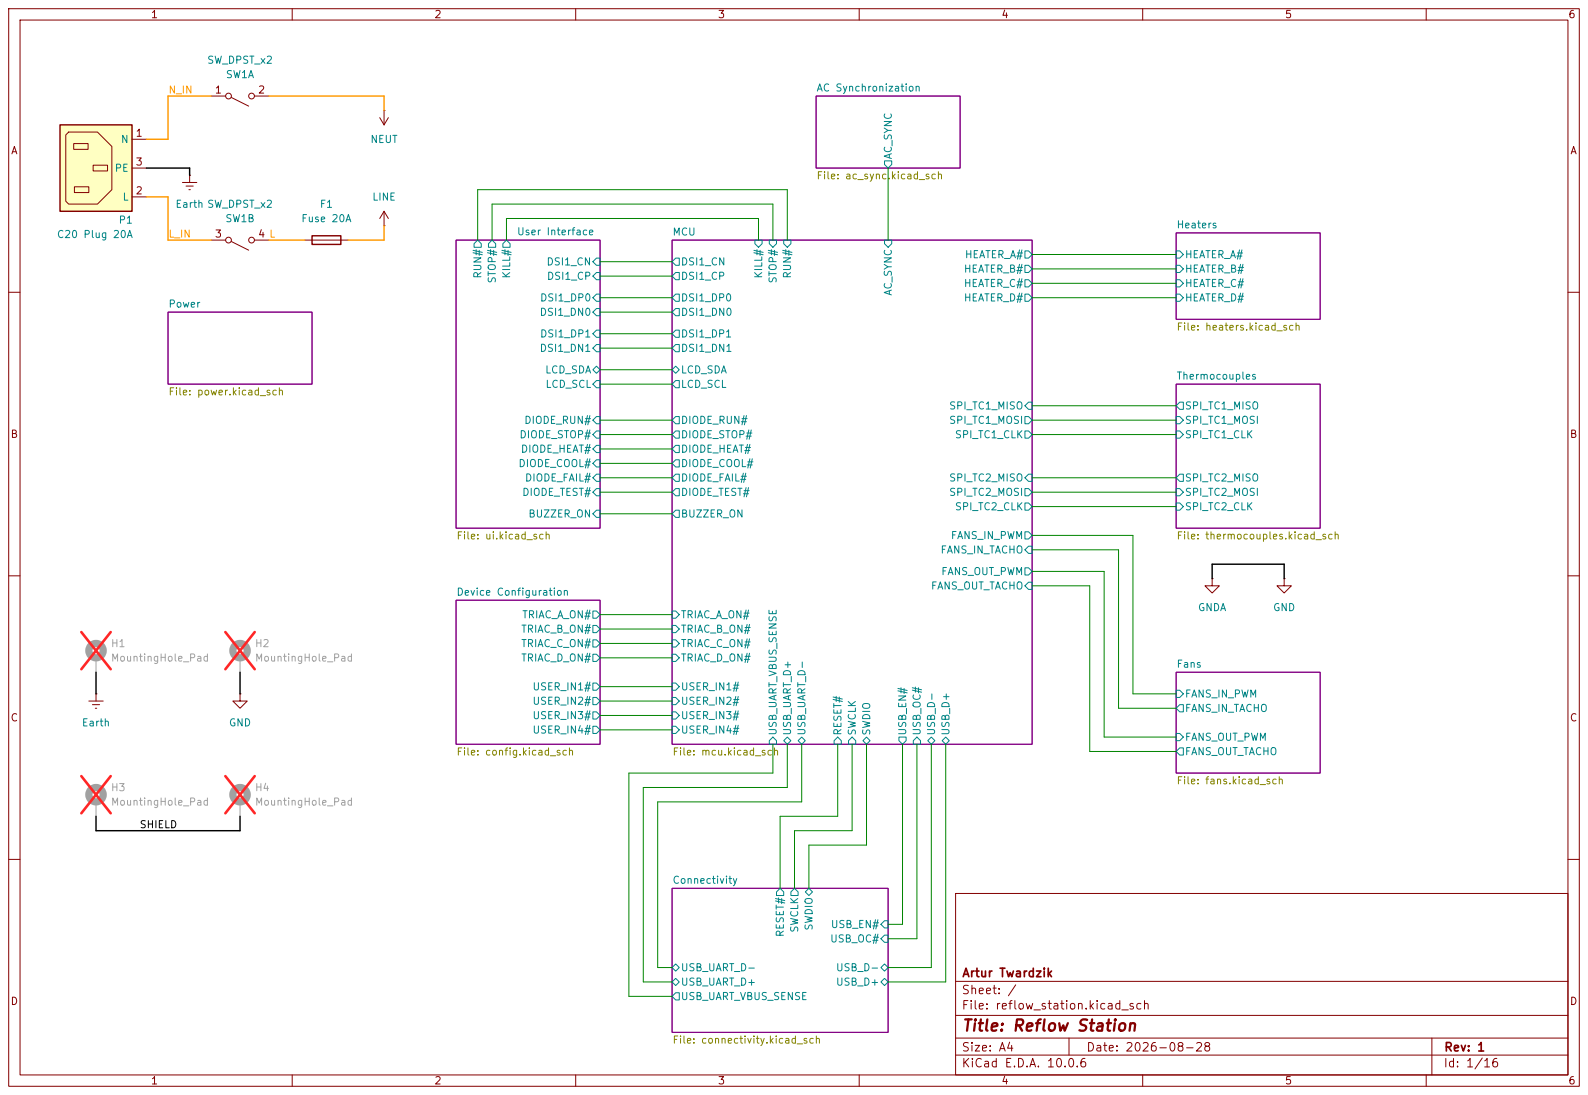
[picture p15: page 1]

Size: A4 | Rev: 1
KiCad E.D.A. 10.0.6 | Id: 1/16

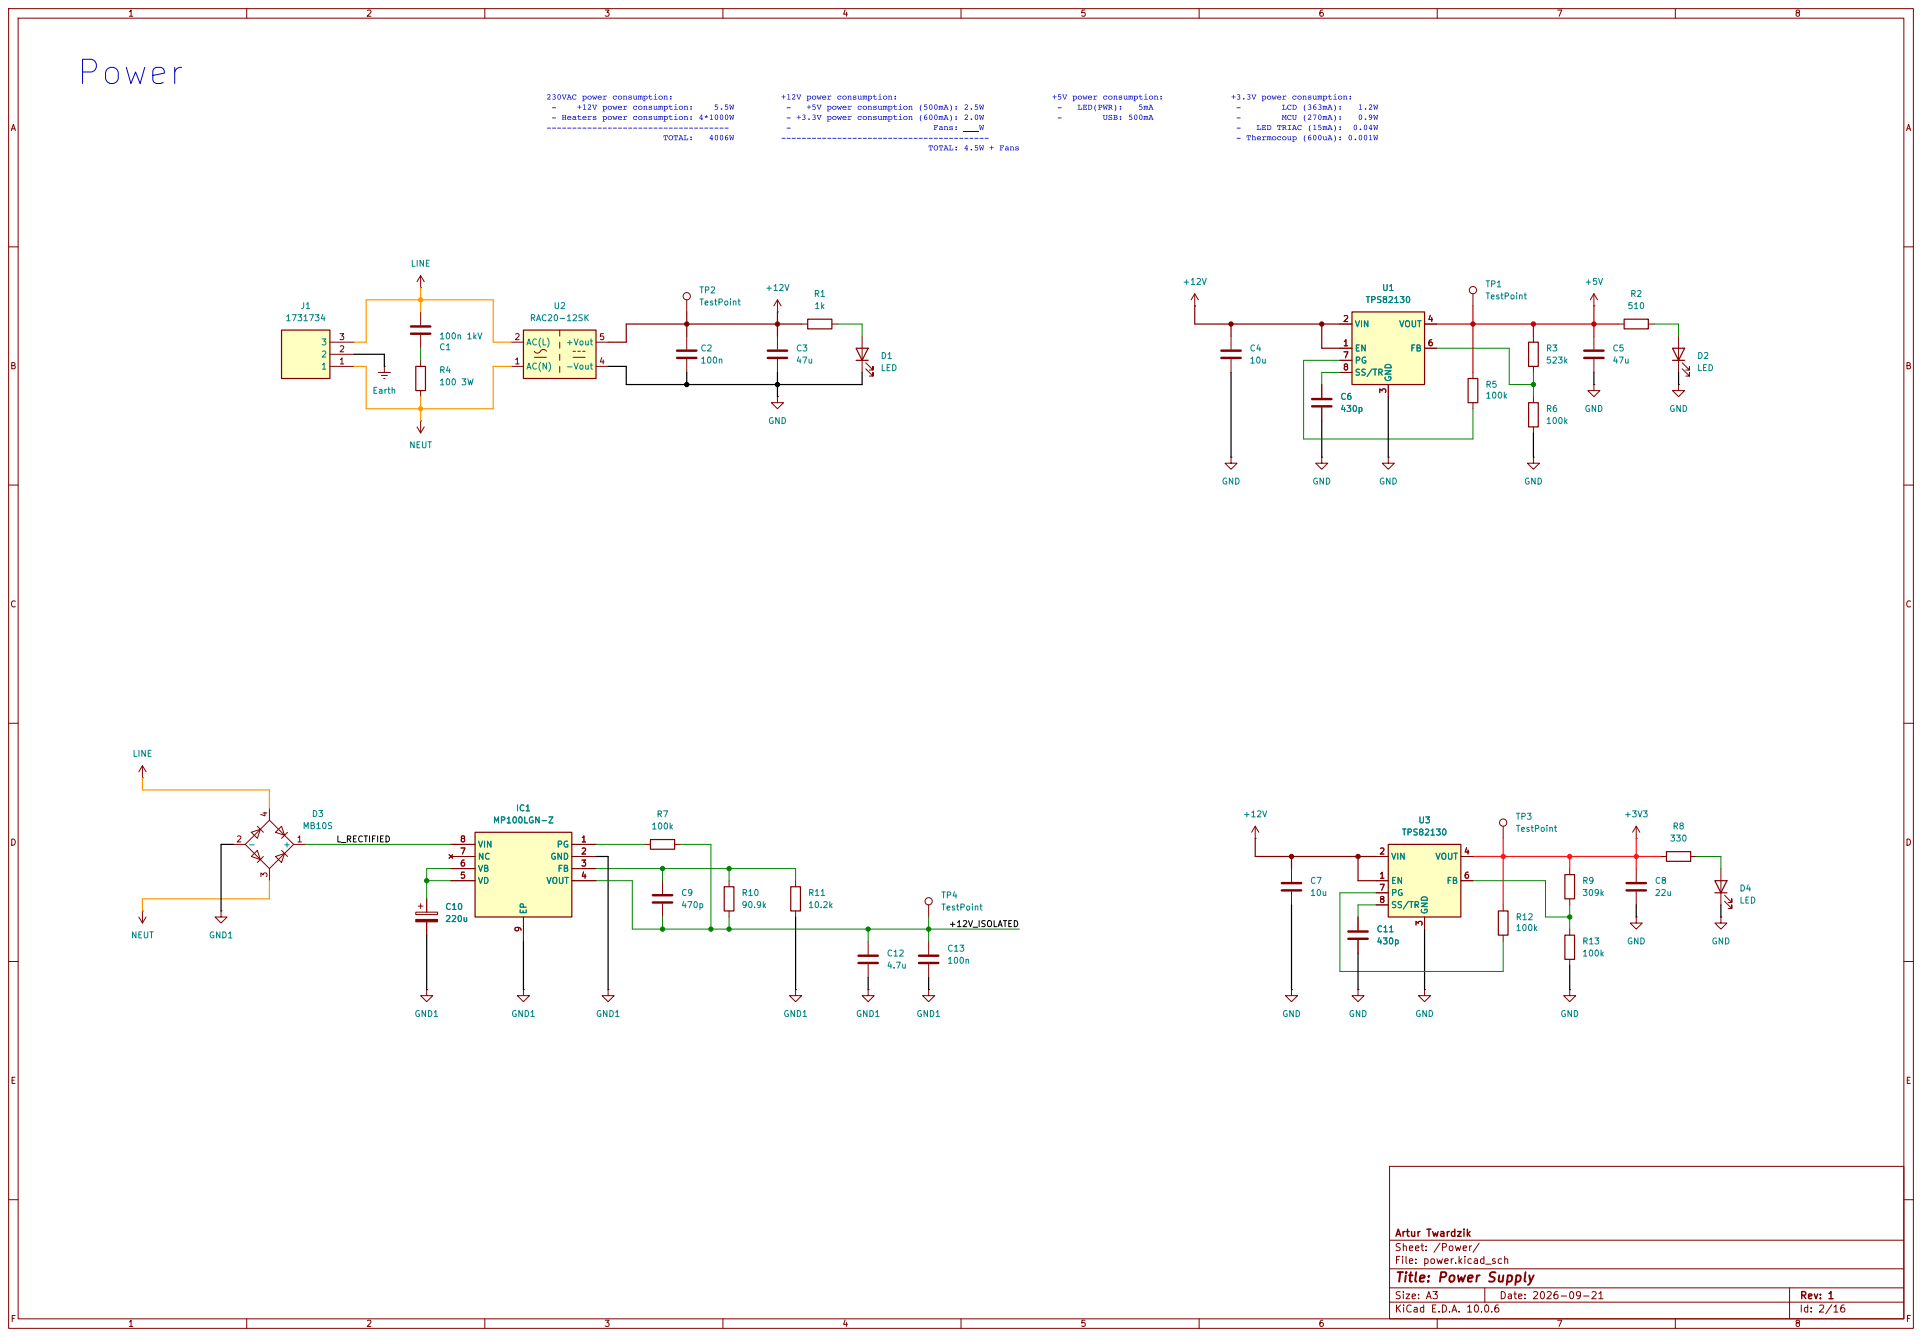
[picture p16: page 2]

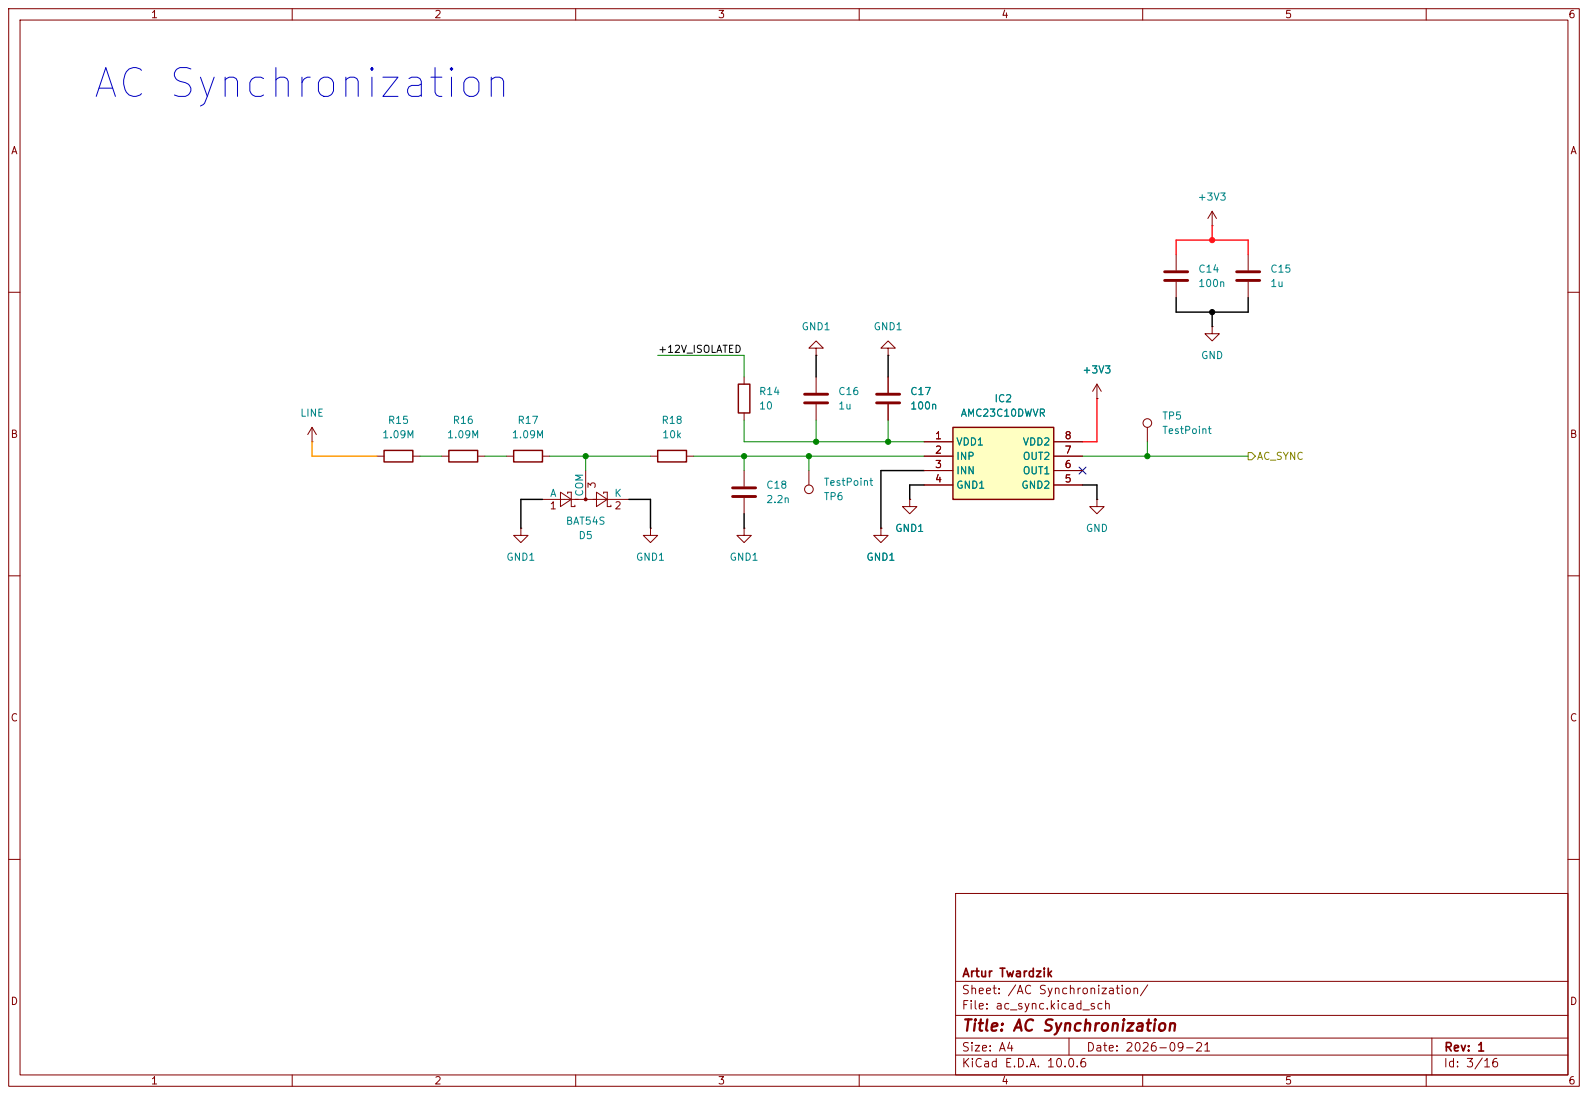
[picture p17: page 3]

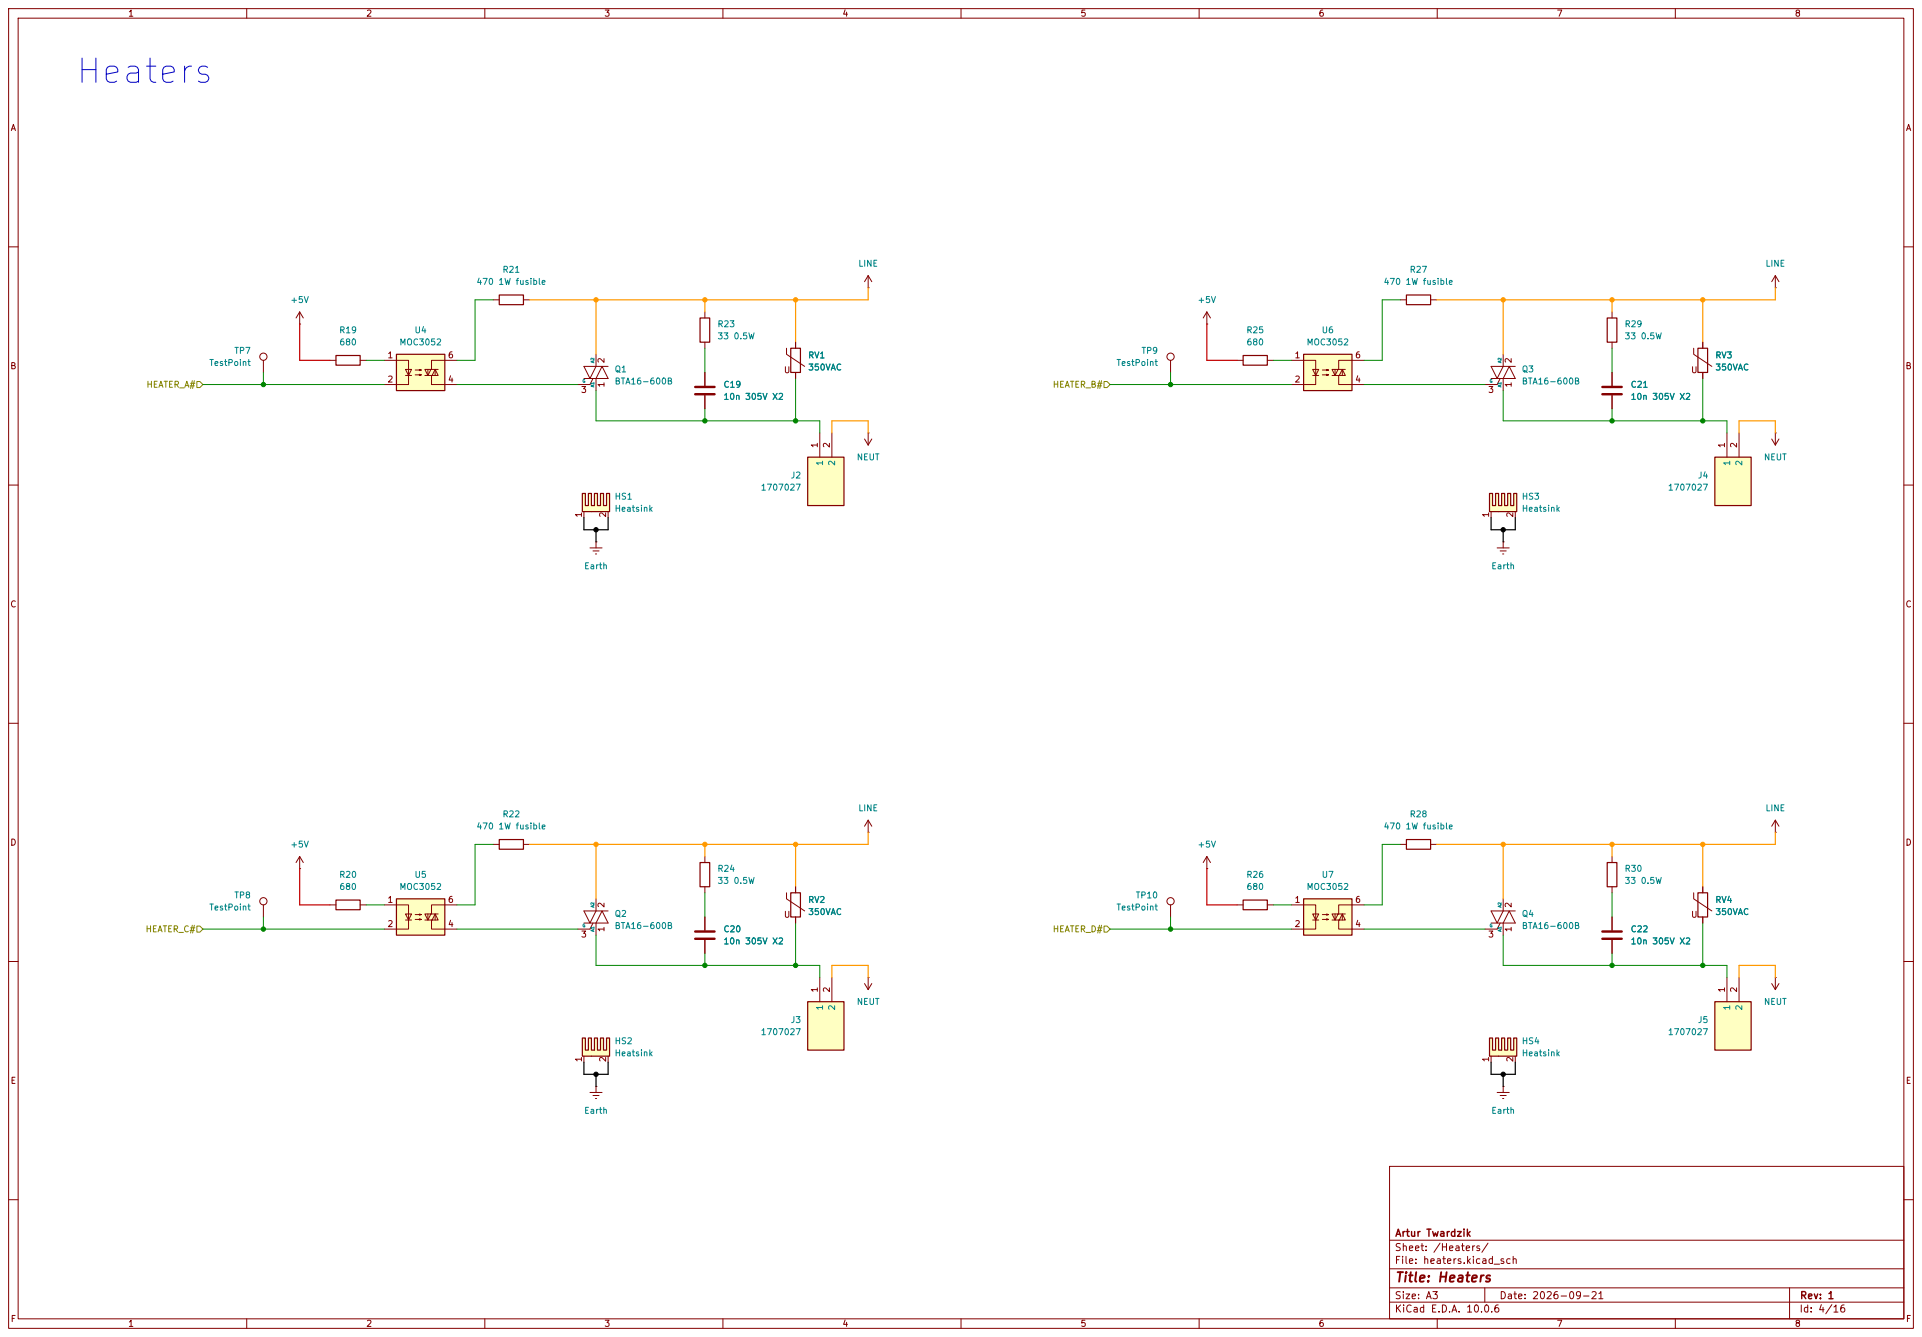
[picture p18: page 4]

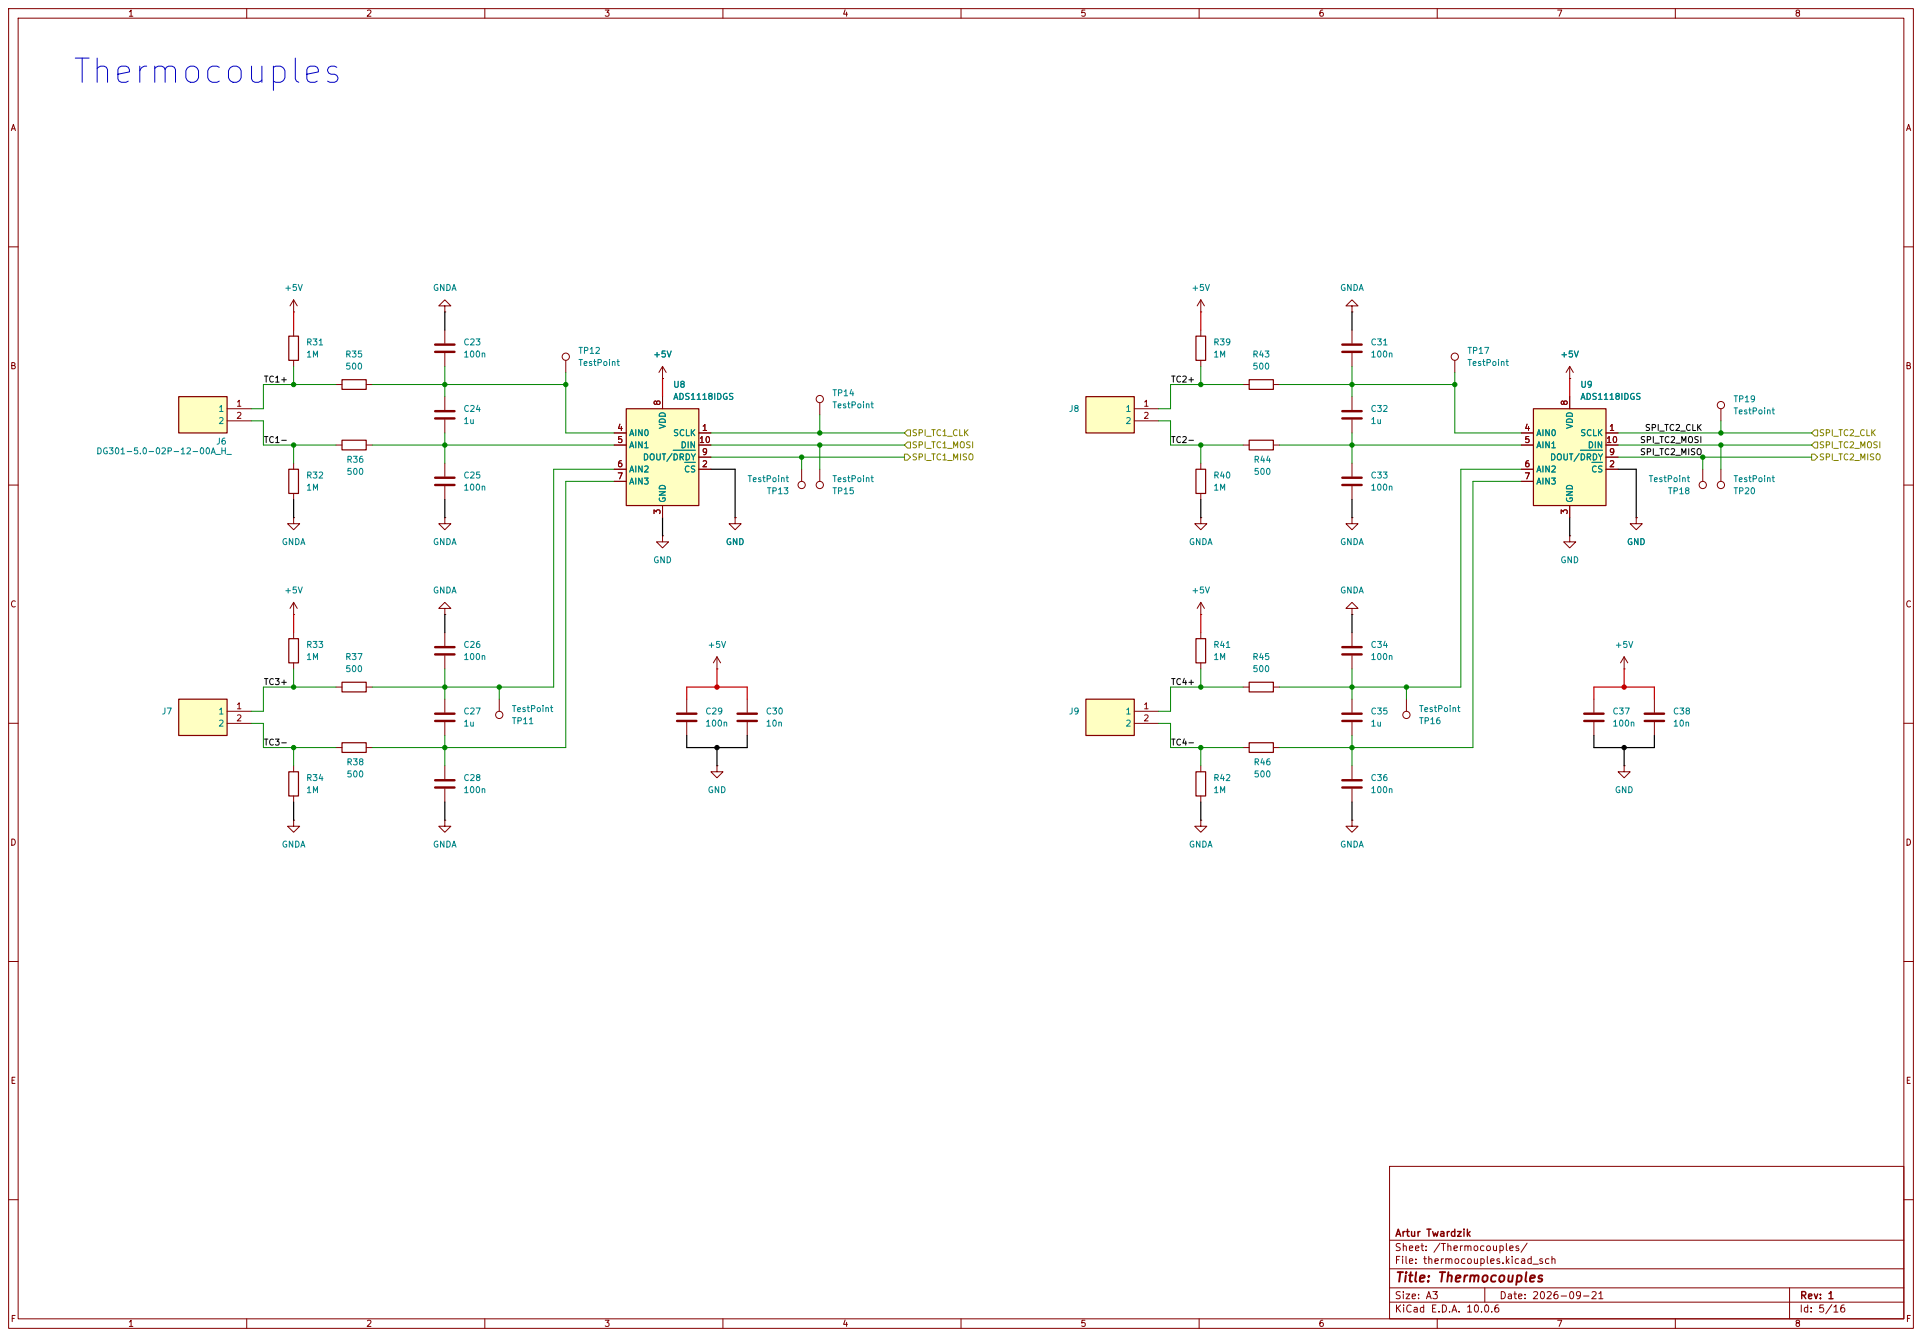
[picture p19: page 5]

8 DOUT/DRDY 9 DIN 10 GND GND U9

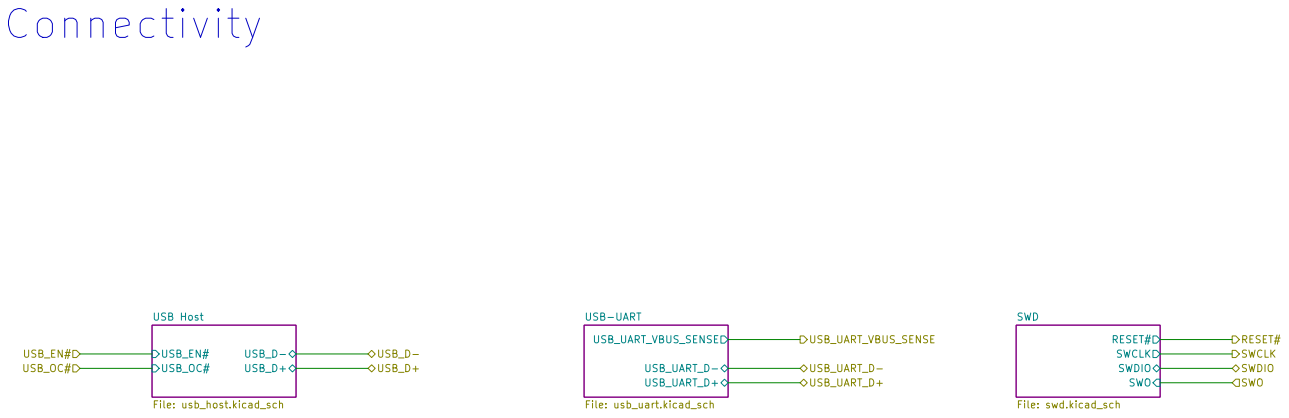
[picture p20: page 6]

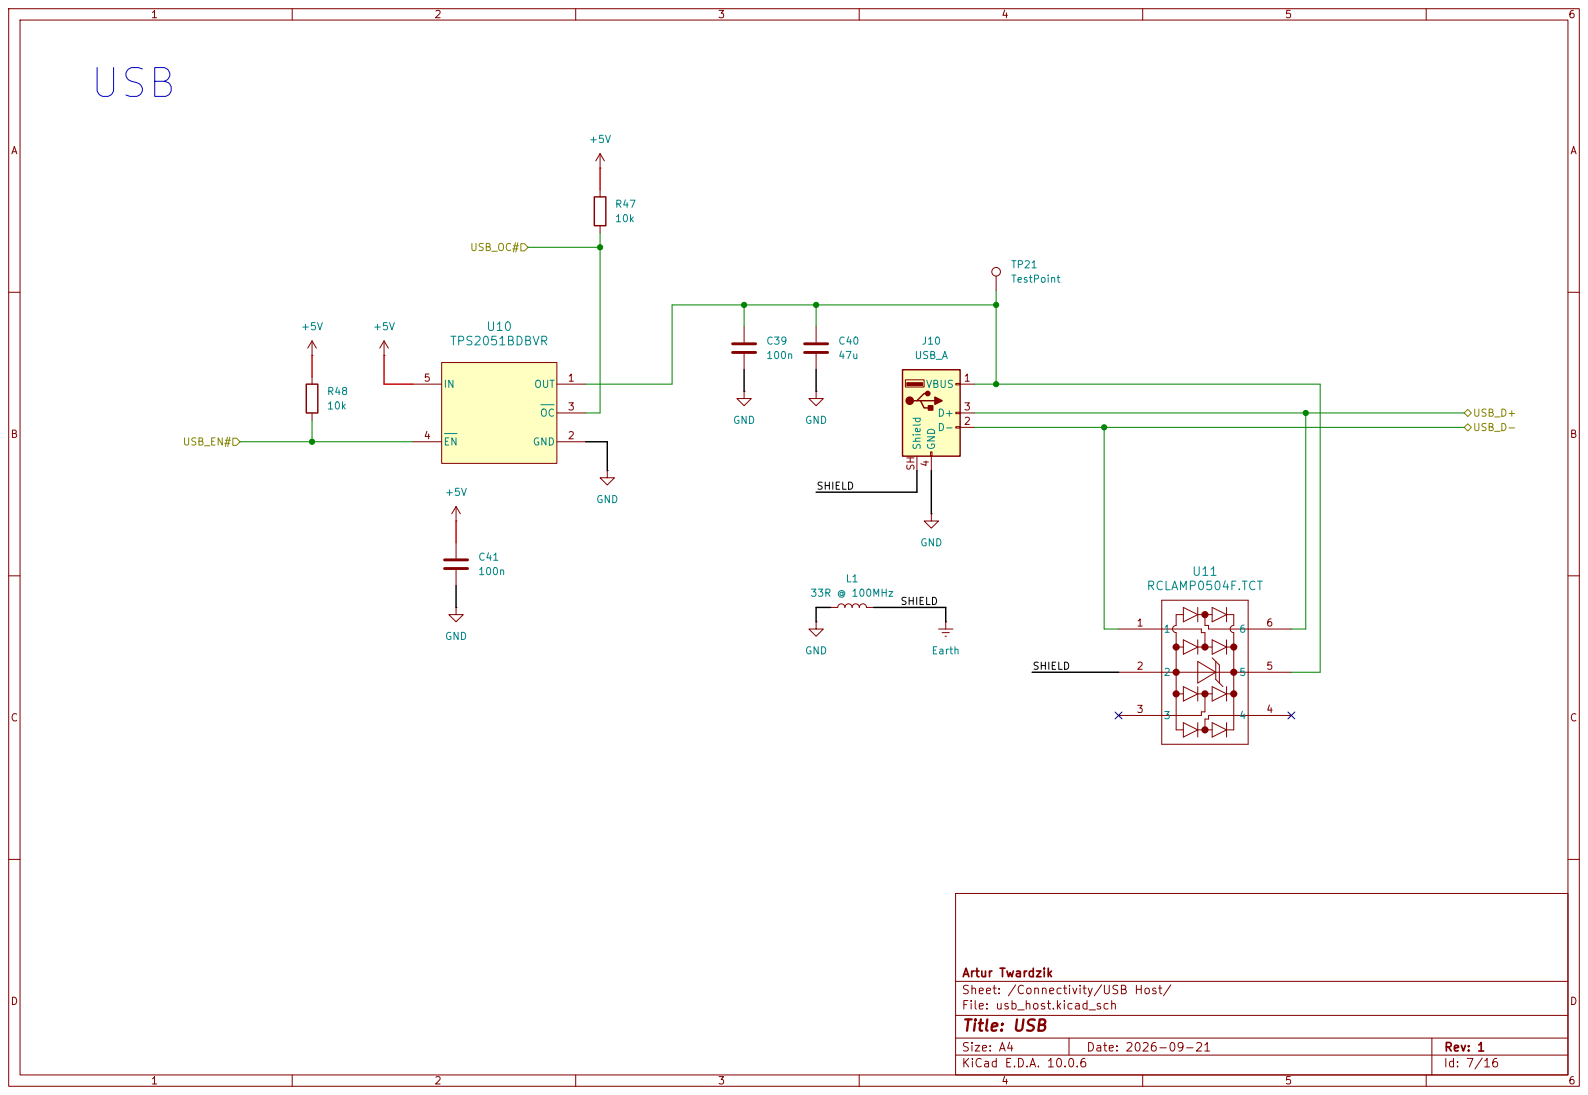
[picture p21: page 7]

Artur Twardzik
Sheet: /Connectivity/USB Host/
File: usb_host.kicad_sch
Title: USB

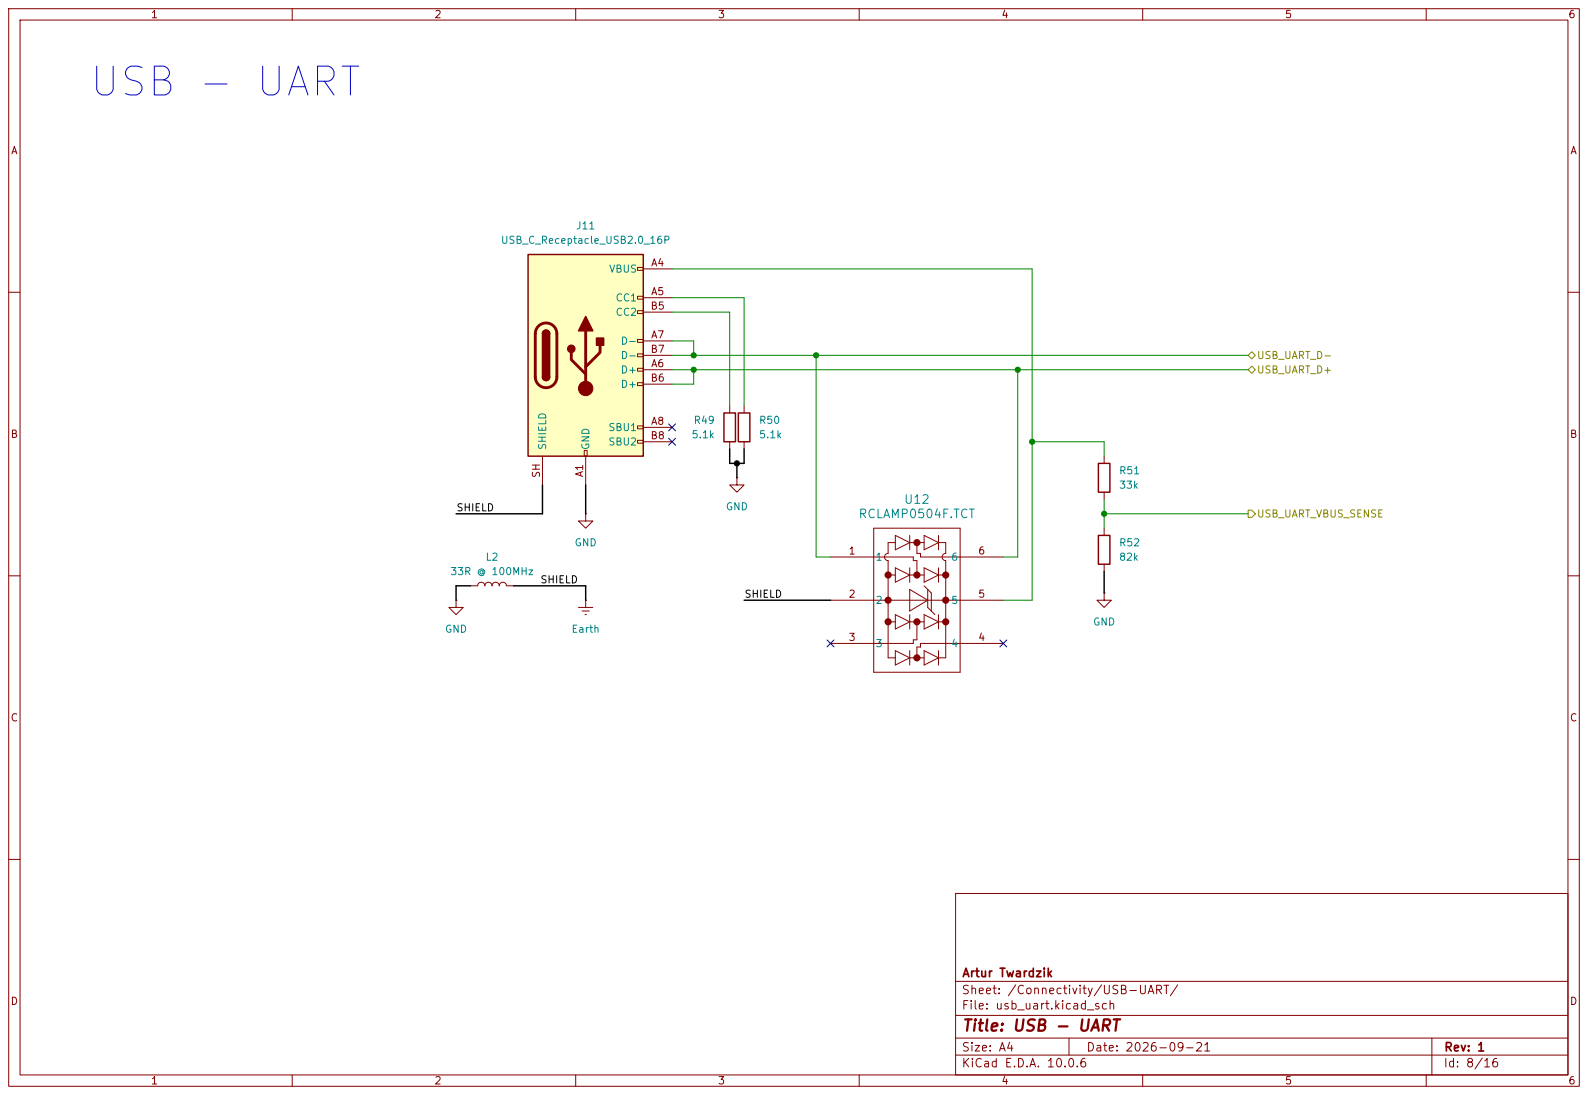
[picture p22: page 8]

Sheet: /Connectivity/USB-UART/
File: usb_uart.kicad_sch
Title: USB - UART

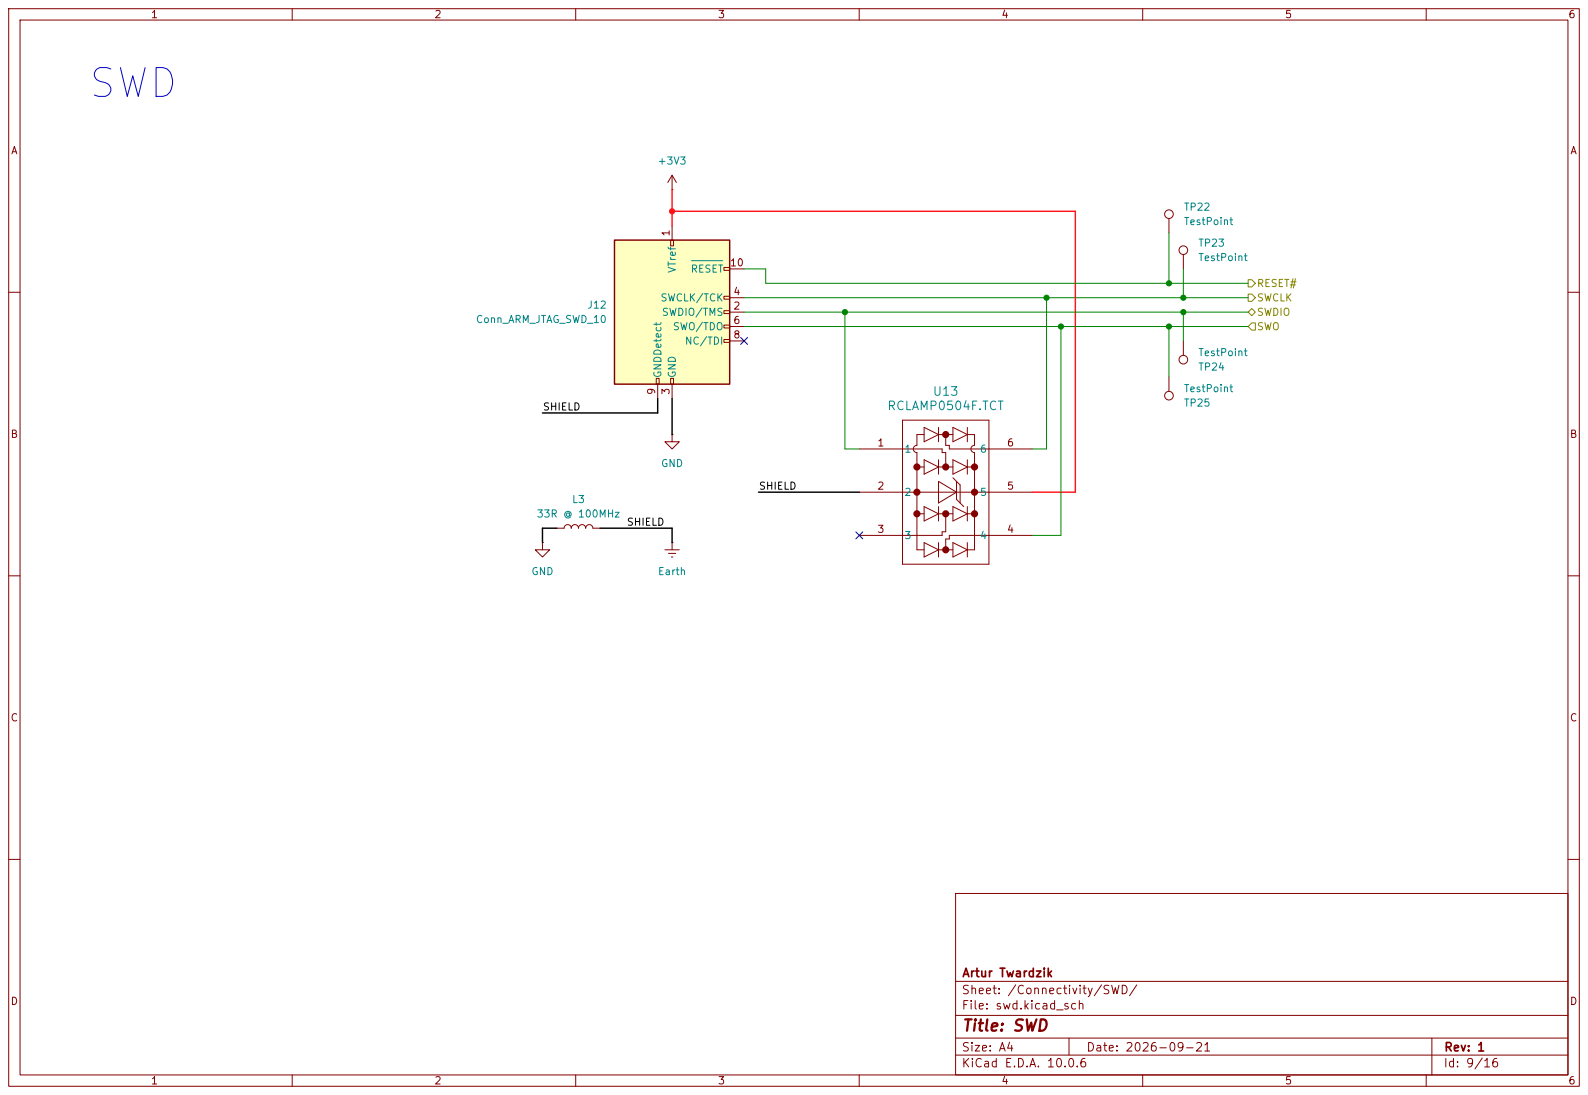
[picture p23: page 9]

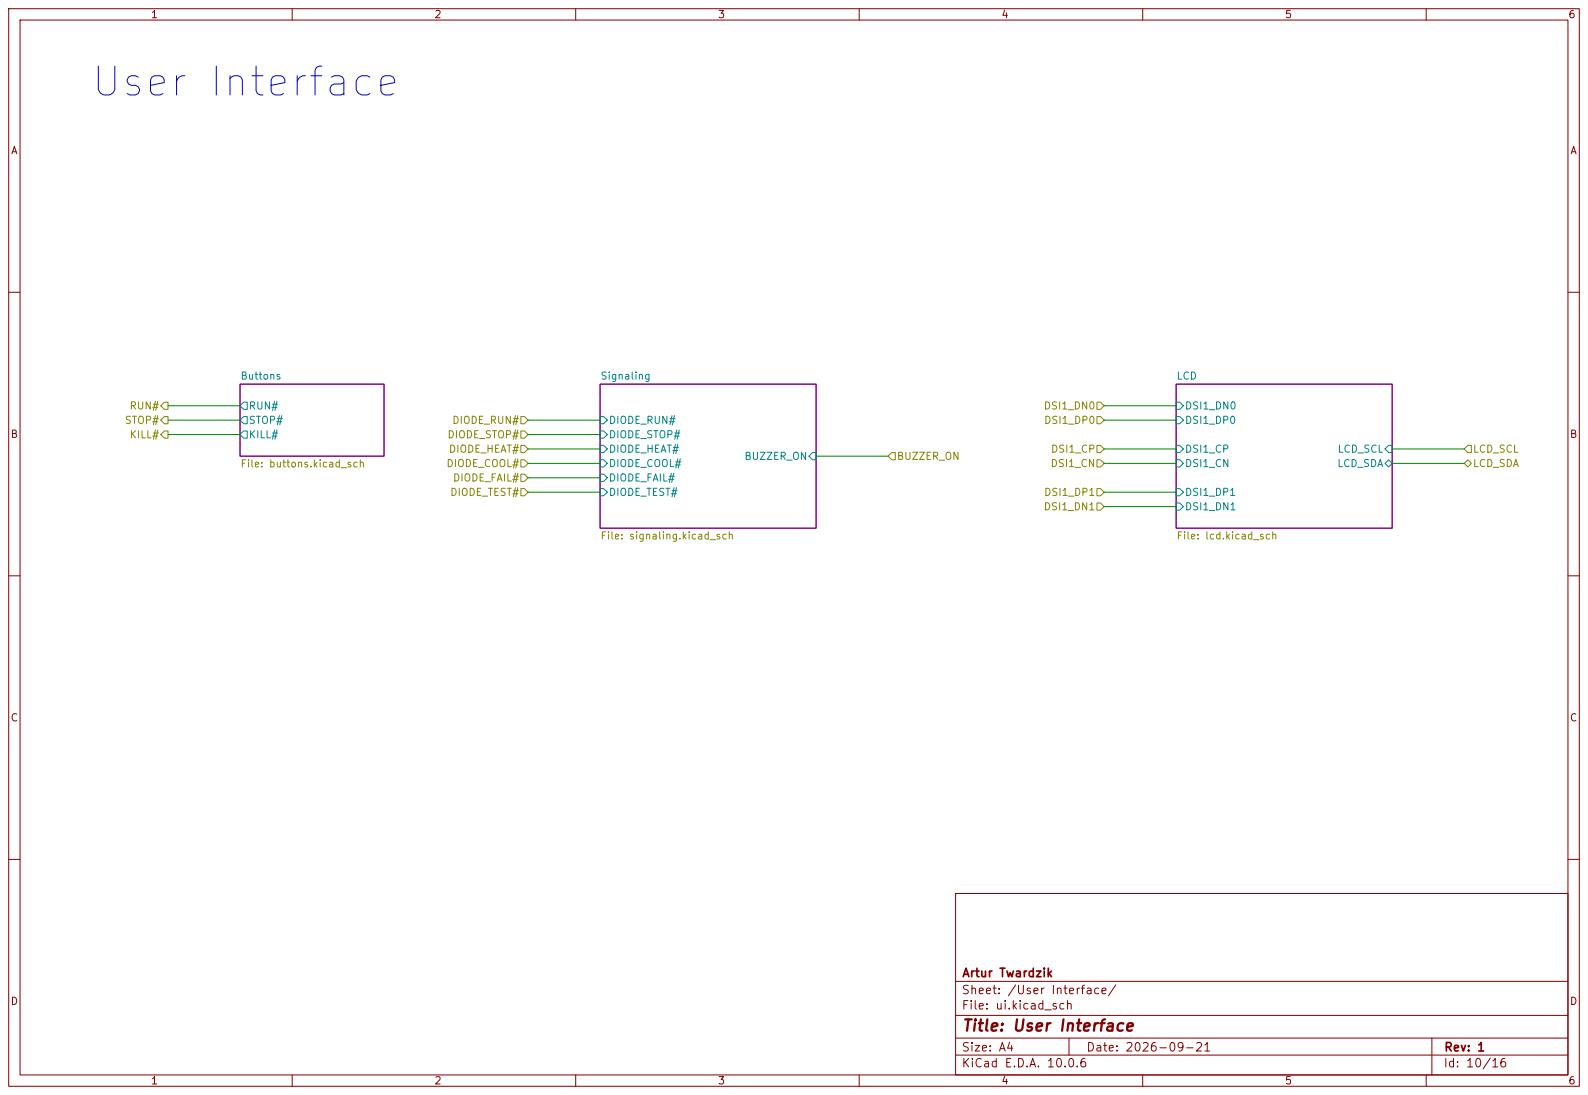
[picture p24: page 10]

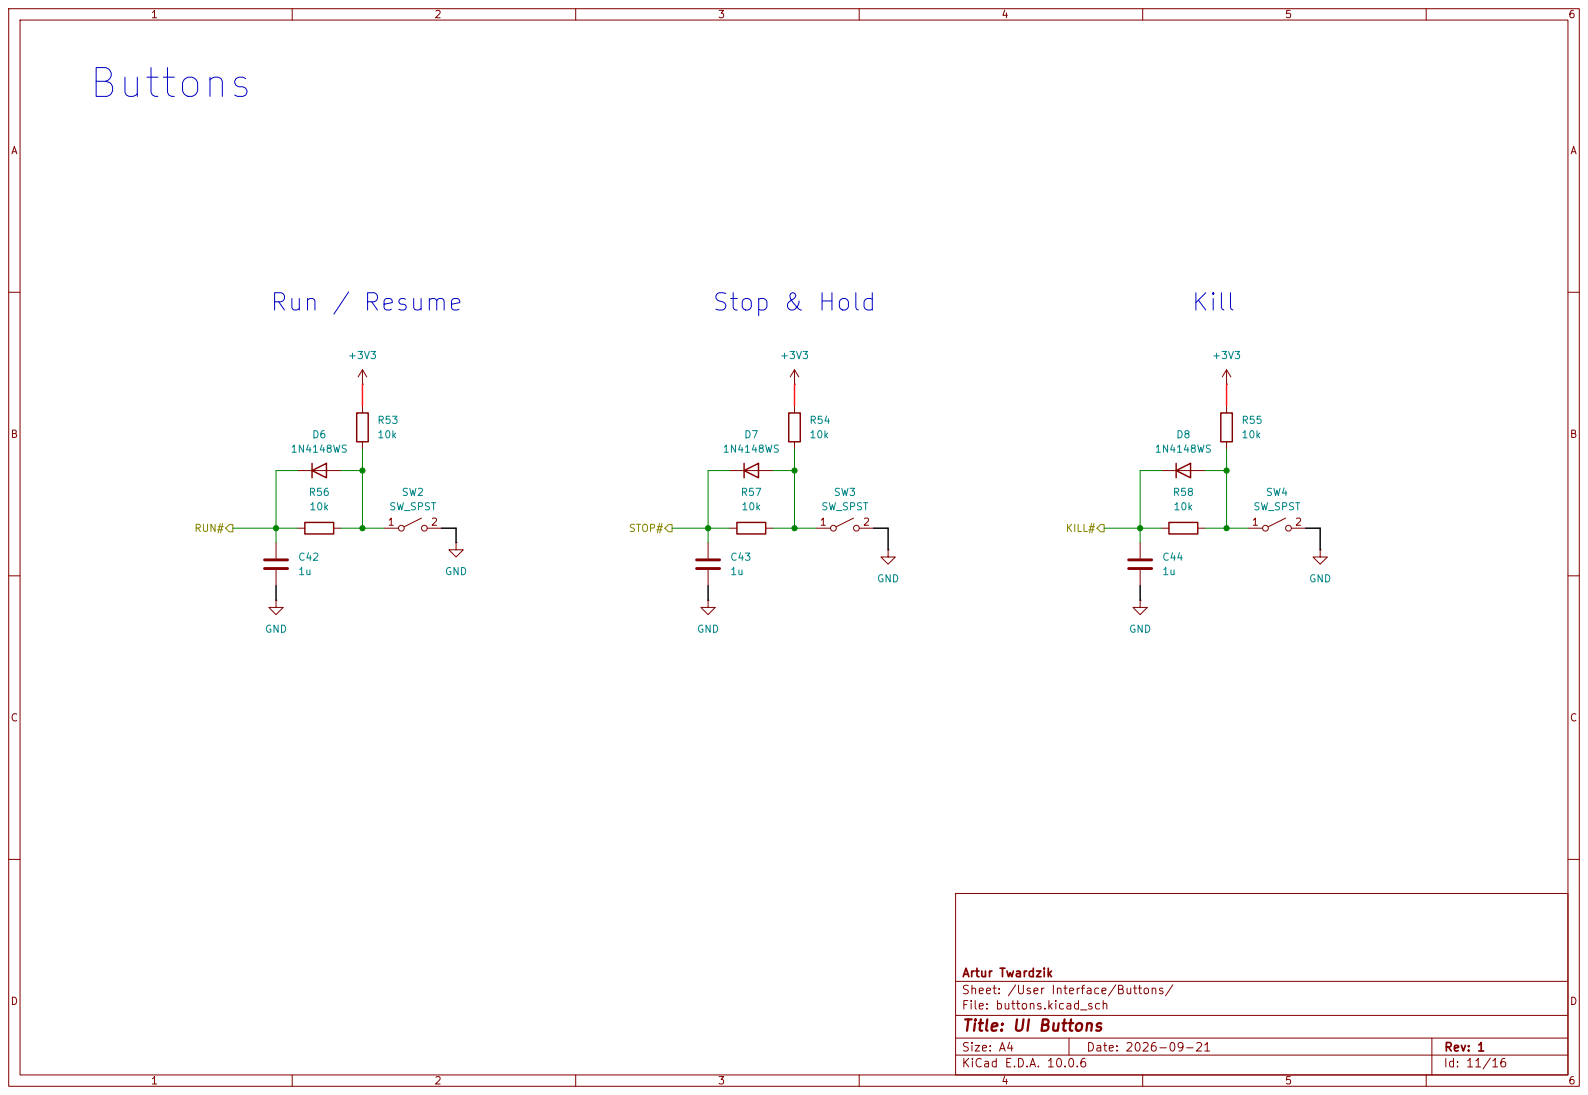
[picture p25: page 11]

Artur Twardzik
Sheet: /User Interface/Buttons/
File: buttons.kicad_sch
Title: UI Buttons

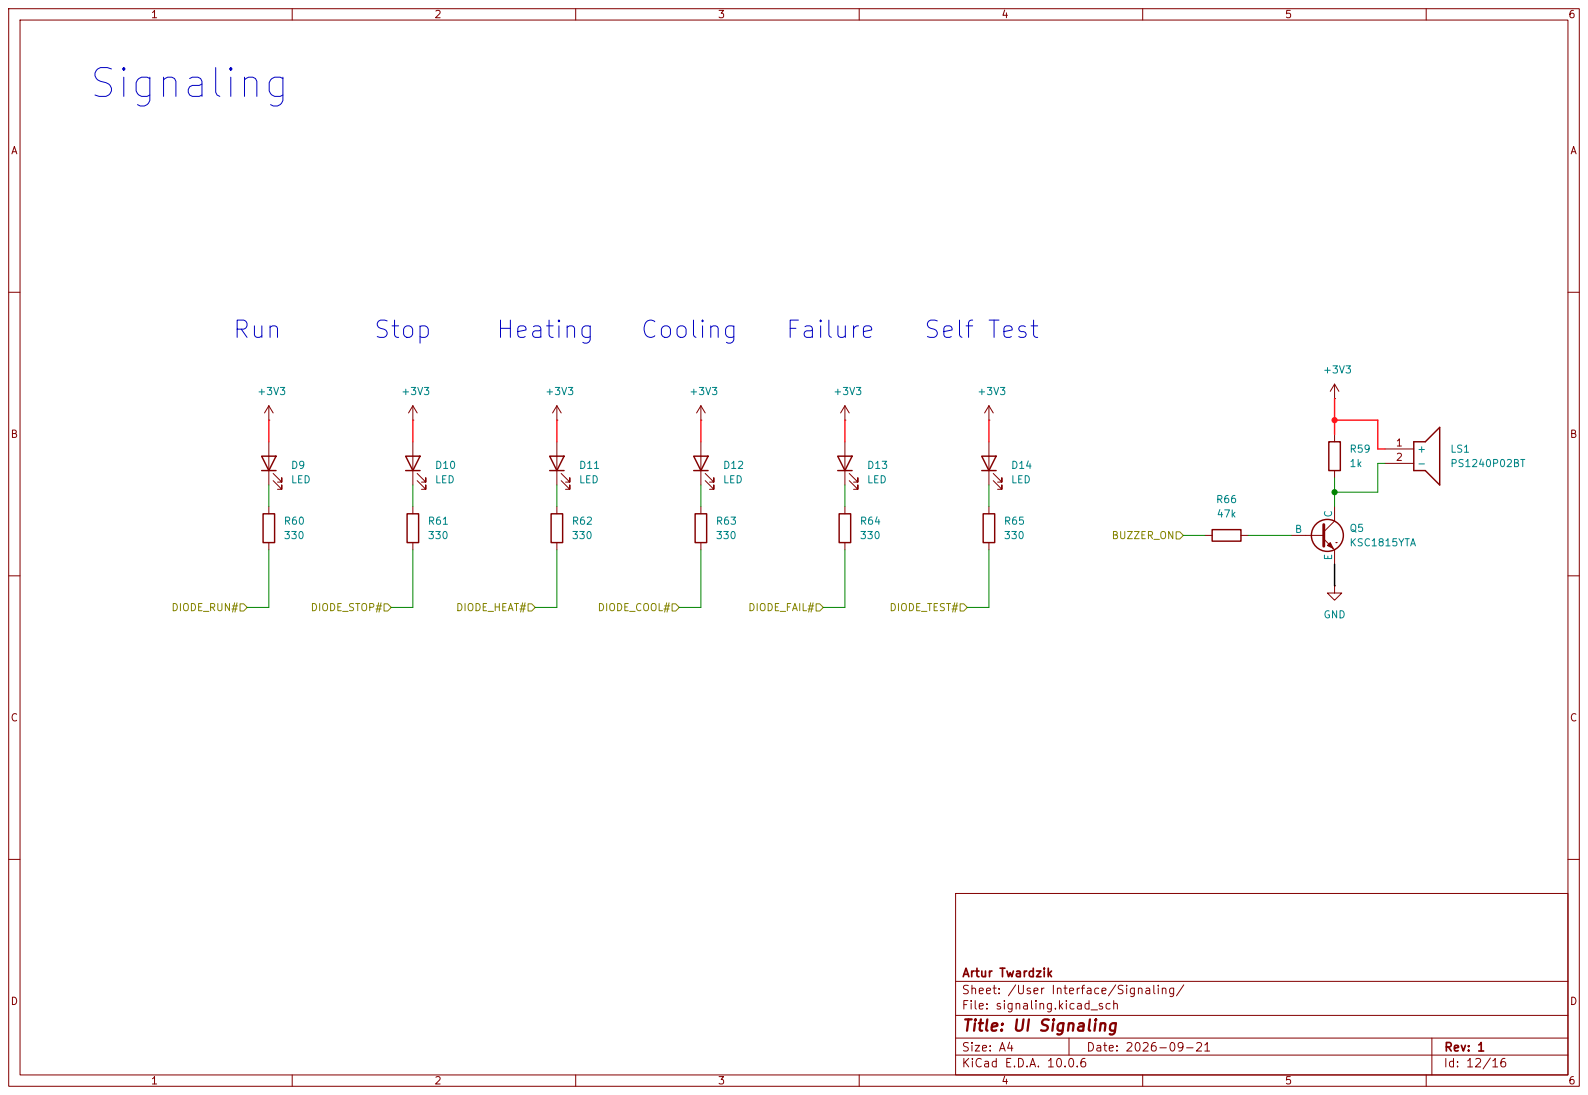
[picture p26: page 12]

Sheet: /User Interface/Signaling/
File: signaling.kicad_sch
Title: UI Signaling


Sheet: /User Interface/LCD/
File: lcd.kicad_sch
Title: UI LCD


Sheet: /Device Configuration/
File: config.kicad_sch
Title: Device Configuration Switches



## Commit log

2026-08-29 Initial commit with basic subsystem
    [reflow_station.kicad_pcb, reflow_station.kicad_sch]
2026-09-02 feat: redesign power from linear regulated with trafo to using buck converters
    [reflow_station.kicad_sch]
2026-09-06 feat: add all peri
    [DBV0005A.stp, reflow_station.kicad_sch]
2026-09-06 fix: replace voltage regulator with modern LDO with automotive qc
    [DCQ0006A.stp, reflow_station.kicad_sch]
2026-09-06 fix: add power rails BEFORE signal diode resistor
    [reflow_station.kicad_sch]
2026-09-10 feat: normalize power section to use one regulator type; add SWD 10 pin connector; add usb-uart IC; add control and signaling; separate heaters
    [MB10S.stp, RAC20-12SK.stp, reflow_station.kicad_sch]
2026-09-11 feat: wire usb to uart and add GNDA for thermocouples
    [reflow_station.kicad_sch]
2026-09-13 feat: connect mcu pins and usb-uart (cdc)
    [reflow_station.kicad_sch]
2026-09-13 feat: add "filter" to heaters and separate shield from GND
    [1731734.stp, PS1240P02BT.stp, reflow_station.kicad_sch]
2026-09-16 feat: add footprints to symbols and extract symbol library
    [1707027.stp, B32921C3103M189.stp, DG301-5.0-02P-12-00A_H_.stp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]
2026-09-16 docs: add README and schematic img inside
2026-09-16 feat: update footprint library and assign 3d models
    [F52Q-1A7H1-11015.stp, MP100LGN-Z.stp, TPS82130SILR.stp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]
2026-09-16 feat: populate elements on board
    [R474N31005001K.stp, reflow_station.kicad_pcb, reflow_station.kicad_sch]
2026-09-16 feat: resize board; position elements more accurately; add mounting holes
    [reflow_station.kicad_pcb, reflow_station.kicad_sch]
2026-09-16 feat: update library; change 2P connector for heaters
    [1731721.stp, reflow_station.csv, reflow_station.kicad_pcb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]
2026-09-19 feat: add proper triac footprint with creepage drill
    [TO-220_V3PBS-1x2,5_a.STEP, reflow_station.csv, reflow_station.kicad_pcb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]
2026-09-19 feat: route high voltage traces
    [reflow_station.kicad_pcb, reflow_station.kicad_sch]
2026-09-21 feat: write down whole BOM
    [reflow_station.csv, reflow_station.kicad_pcb, reflow_station.kicad_sch]
2026-09-21 feat: change flat schematic to hierarchical, change board dimensions and add keepout areas
    [ac_sync.kicad_sch, buttons.kicad_sch, config.kicad_sch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]
2026-09-21 feat: add board dimensions and change mcu position
    [config.kicad_sch, fans.kicad_sch, heaters.kicad_sch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]
2026-09-23 feat: add ground and earth(shield) planes, add better - multi layer connection for AC mains connector
    [ac_sync.kicad_sch, config.kicad_sch, power.kicad_sch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]
2026-09-23 feat: add power planes and move voltage regulators closer to their usage
    [heaters.kicad_sch, reflow_station.csv, reflow_station.kicad_pcb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]
2026-09-24 feat: route USB differential traces
    [ac_synch.kicad_sch, config_switches.kicad_sch, reflow_station.kicad_pcb]
2026-09-24 feat: calculate and sketch differential pairs for MIPI DSI
    [reflow_station.kicad_pcb]
2026-09-27 feat: tune differential pairs and reorder thermocouple sockets
    [lcd.kicad_sch, reflow_station.kicad_pcb]
2026-09-27 feat: route thermocouples, USB ports and DSI
    [mcu.kicad_sch, reflow_station.kicad_pcb]
2026-09-28 feat: route config switches and SWD debug
    [mcu.kicad_sch, reflow_station.kicad_pcb, swd.kicad_sch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]
2026-09-29 feat: route remaining traces
    [ac_sync.kicad_sch, buttons.kicad_sch, config.kicad_sch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]
2026-09-29 feat: follow pcb guidelines for thermocouples by changing capacitor and resistor positions; separate reference planes for TCs
    [reflow_station.kicad_pcb, thermocouples.kicad_sch]
2026-10-12 chore: update to the latest kicad state
2026-10-12 chore: delete old schematic svg file
2026-10-12 feat: update BOM file
